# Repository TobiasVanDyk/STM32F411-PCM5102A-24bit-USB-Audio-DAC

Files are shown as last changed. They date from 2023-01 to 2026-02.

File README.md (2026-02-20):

# STM32F411 PCM5102A 24bit USB Audio DAC

This is an inexpensive USBAudio DAC that supports 24-bit resolution audio at 44.1kHz, 48kHz or 96kHz. It uses an STM32F411 Black Pill with two different i2s PCM5102A DAC modules - they differ in size and design. The software is based on this [**STM32F4xx USB to I2S DAC Audio Bridge**](https://github.com/har-in-air/STM32F411_USB_AUDIO_DAC) and the [**issue as discussed here**](https://github.com/har-in-air/STM32F411_USB_AUDIO_DAC/issues/7).

Two sizes of the DAC were made - the larger size module uses a PCM5102A DAC with three LDO regulators but with no mute control pin, and the (much) smaller sized DAC uses two LDO regulators and has a mute control pin. 

Note that the [**BambooMaster RP2040 DAC**](https://github.com/BambooMaster/usb_sound_card_hires), which is further [**described here**](https://github.com/TobiasVanDyk/Pico-MCU-from-Raspberry-Pi/tree/main/DacPico), *sounds at least as good as the two STM32F411 DACs presented here*.

The volume control code modifications as discussed in the issue linked to above, was added to a windows port of the code. The Windows 10 STM32CubeIDE project is included here as F411_USB_I2S.zip and the binaries are in build.zip - the hex file can directly be uploaded via the STM32CubeProgrammer using a standard ST-Link module. Note all licenses applicable are the original source code licenses. 

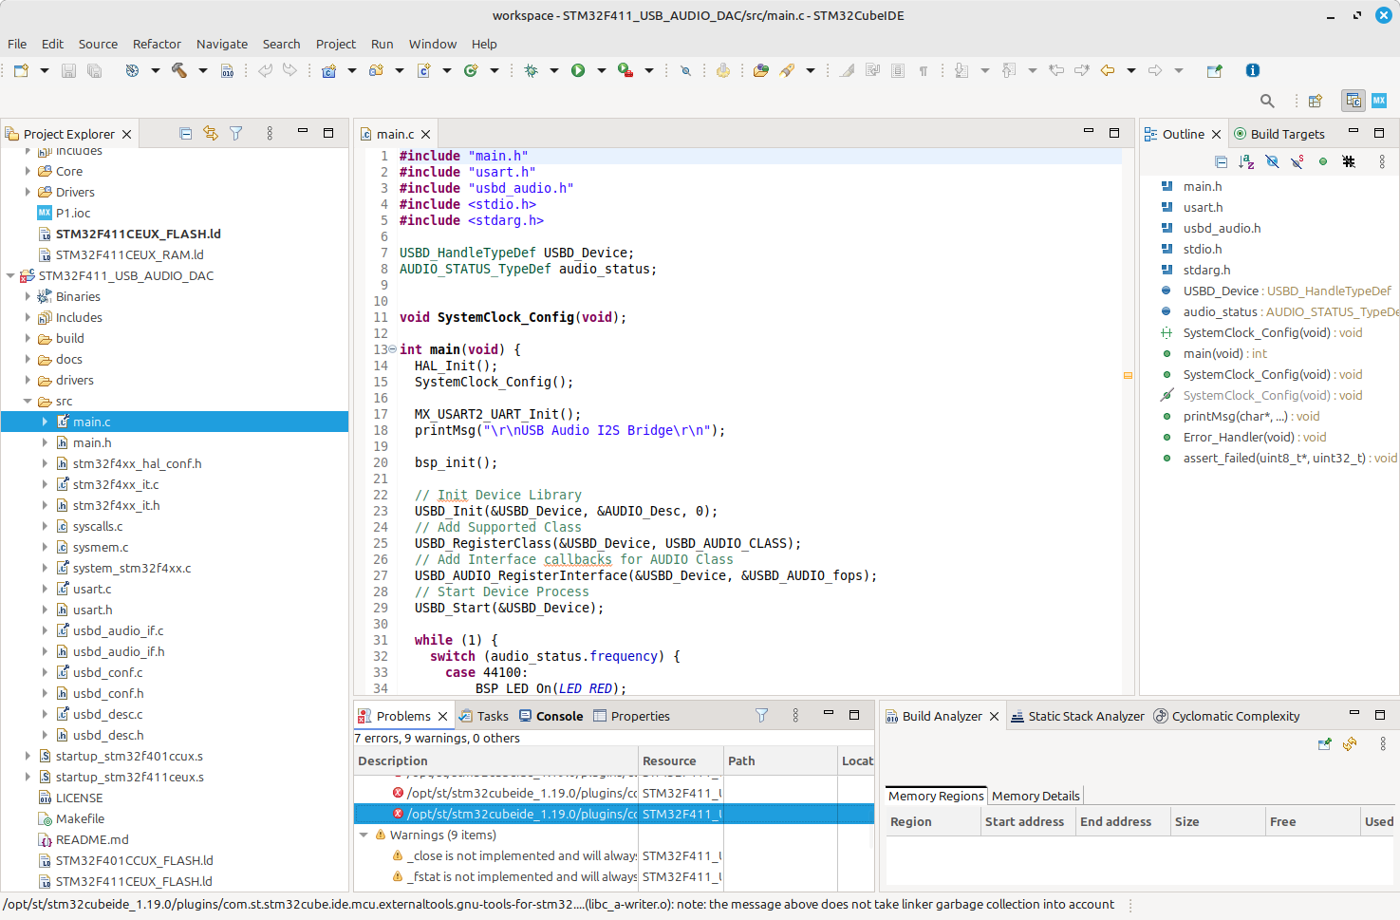
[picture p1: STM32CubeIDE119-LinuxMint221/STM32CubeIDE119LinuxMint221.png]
**Current (July 2025) source and build binaries**, using STM32CubeIDE-1.19.0 and STM32F411-1.28.1, are in the folder [**STM32CubeIDE119-LinuxMint221**](https://github.com/TobiasVanDyk/STM32F411-PCM5102A-24bit-USB-Audio-DAC/blob/main/STM32CubeIDE119-LinuxMint221). They were built using make from a terminal and also using STM32CubeIDE, following the instructions as in [**USB DAC Audio**](https://github.com/har-in-air/STM32F411_USB_AUDIO_DAC). Note that when building using the IDE, there are a **number of linker errors** , but binaries were nonetheless built (and tested). The only source code change made was in main.c to the LED code - using two instead of three LEDs to indicate the three frequency states. The Makefile file was edited for a PCM5102A DAC. Note that the project was imported using **File -> New -> Other -> C/C++ -> Makefile Project with existing code** - an empty project named P1 was created before this and used to import the STM32F4xxx firmware (version 1.28.1). Nothing else was required the build the USB-AudioDAC project using STM32CubeIDE. 

The [**previous source**](https://github.com/har-in-air/STM32F411_USB_AUDIO_DAC/issues/14) build binaries are in build-24March2023.zip, built using STM32CubeIDE version 1.12. Older source (Feb 2023) binaries are in build-linux3.tar.gz (Linux Mint 21.1 with STM32CubeIDE 1.11.2), and build-win10.zip (based on project files STM32F411_USB_AUDIO_DAC-win10.zip), built on Windows 10 using the same version of STM32CubeIDE.

For [**older detailed instructions**](https://github.com/TobiasVanDyk/STM32F411-PCM5102A-24bit-USB-Audio-DAC/blob/main/Linux-Mint-211-and-Windows-10-compiling-and-uploading-the-STM32F411-USB-Audio-DAC-fi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), in setting up STMCube 1.11 and 1.12, refer to the PDF document: Installing STM32CubeIDE in Linux Mint 21.1 and in Windows 10, and compiling and uploading the STM32F411 USB Audio DAC firmware.

The USB DAC with the volume control identifies as PCM5102A DAC and the older non-volume version as USB to I2S DAC - refer to the screen dump shown below.

<p align="left">
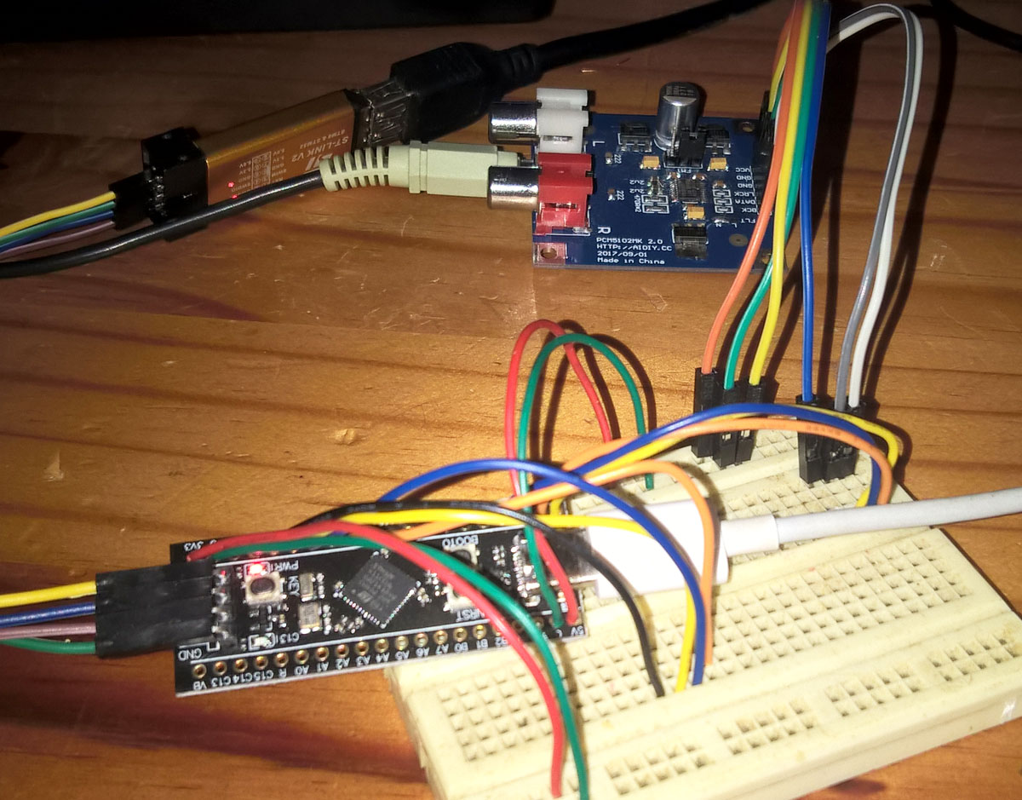
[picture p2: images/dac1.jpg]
 
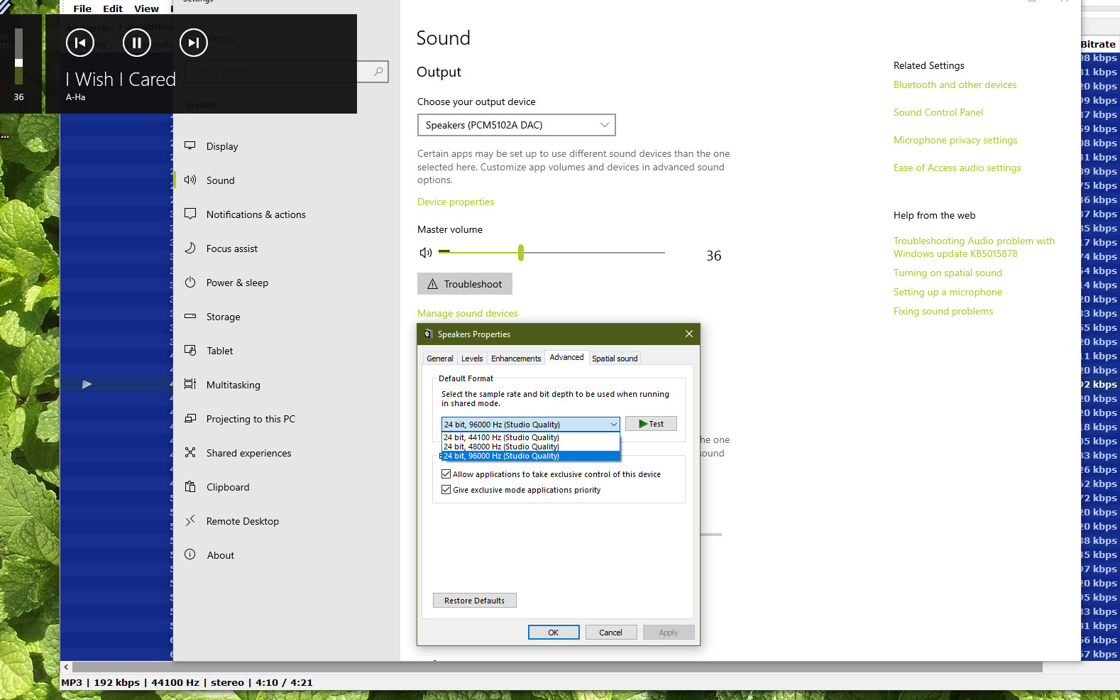
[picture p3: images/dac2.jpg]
 
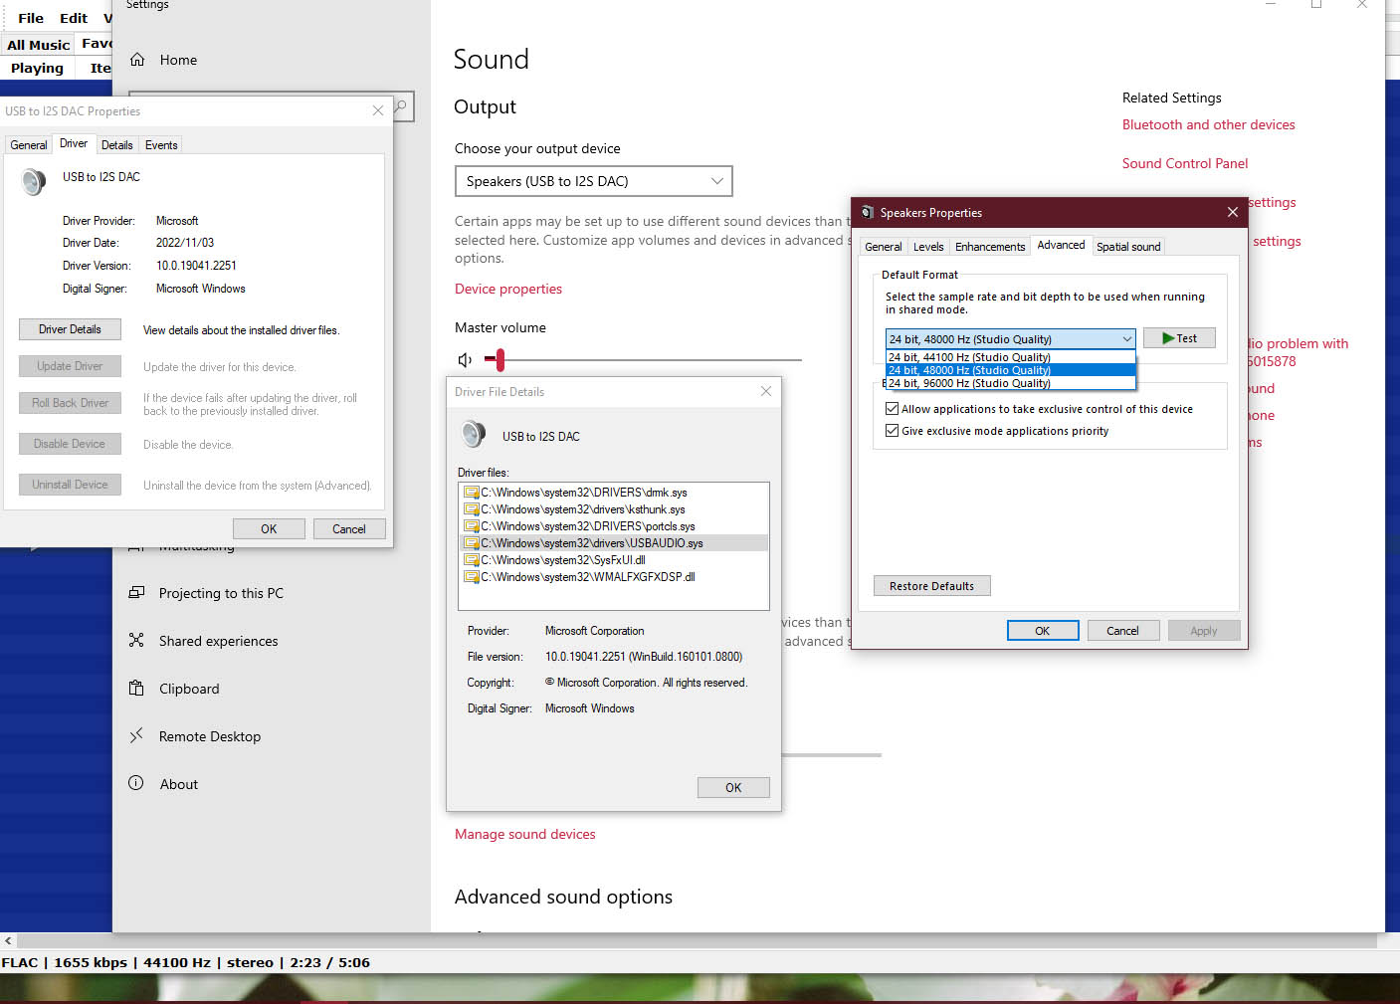
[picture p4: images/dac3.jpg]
 
</p>

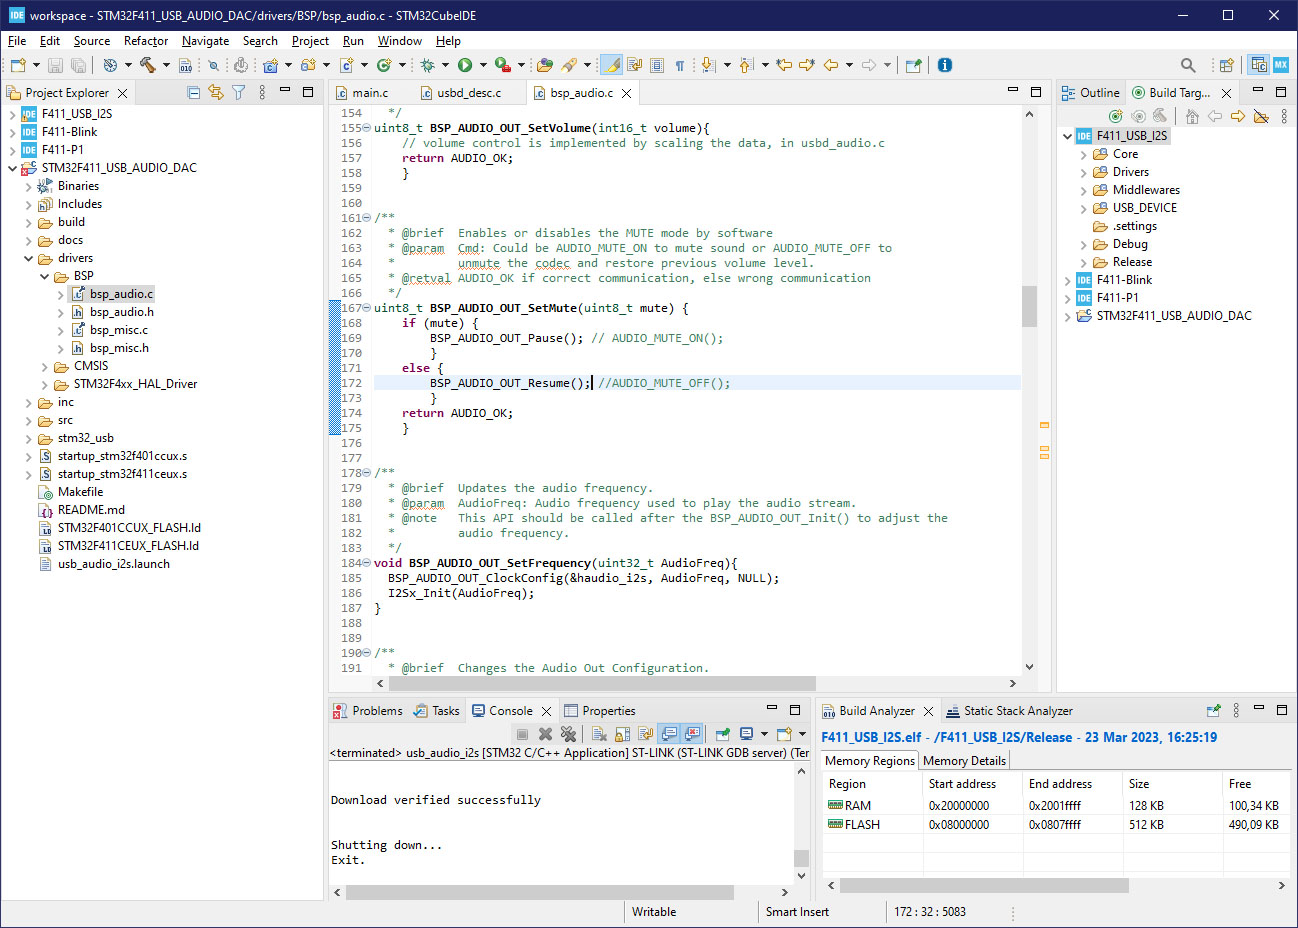
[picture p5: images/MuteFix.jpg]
 The larger sized PCM5102A DAC module used does not have a hardware mute breakout pin. Two changes to bsp_audio.c gives an alternative "volume mute" - the compiled version is in MuteFix.zip. This version uses only the red and green LEDs to indicate the three frequency modes - those changes are in main.c
``` 
uint8_t BSP_AUDIO_OUT_SetMute(uint8_t mute) {
	if (mute) {
		BSP_AUDIO_OUT_Pause();  // AUDIO_MUTE_ON();
		}
	else {
		BSP_AUDIO_OUT_Resume(); // AUDIO_MUTE_OFF();
		}
	return AUDIO_OK;
	}

``` 

**Connections for the larger-sized DAC:**
``` 
F411    PCM5102A    LED    Description 
--------------------------------------------------------------------
5V      VCC
GND     GND            
B13     BCK                I2S_BCK (Bit Clock)
B15     Data               I2S_SDI (Data Input)
B12     LRCK               I2S_WS (LR Clock)
-------------------------------------------------------------------- 
B3                 RED     Fs = 96kHz (all 220R to 3v3)
B6                 GRN     Fs = 48kHz (Red+Green for 44.1kHz)
3v3                LED through-hole common
 
C13             On-board   Diagnostic Blue LED
--------------------------------------------------------------------
``` 
<p align="left">
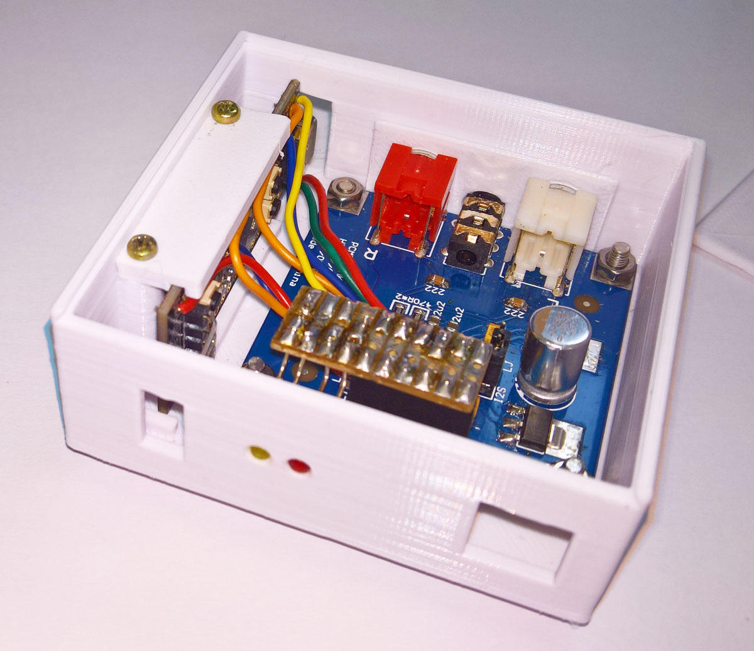
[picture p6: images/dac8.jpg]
 
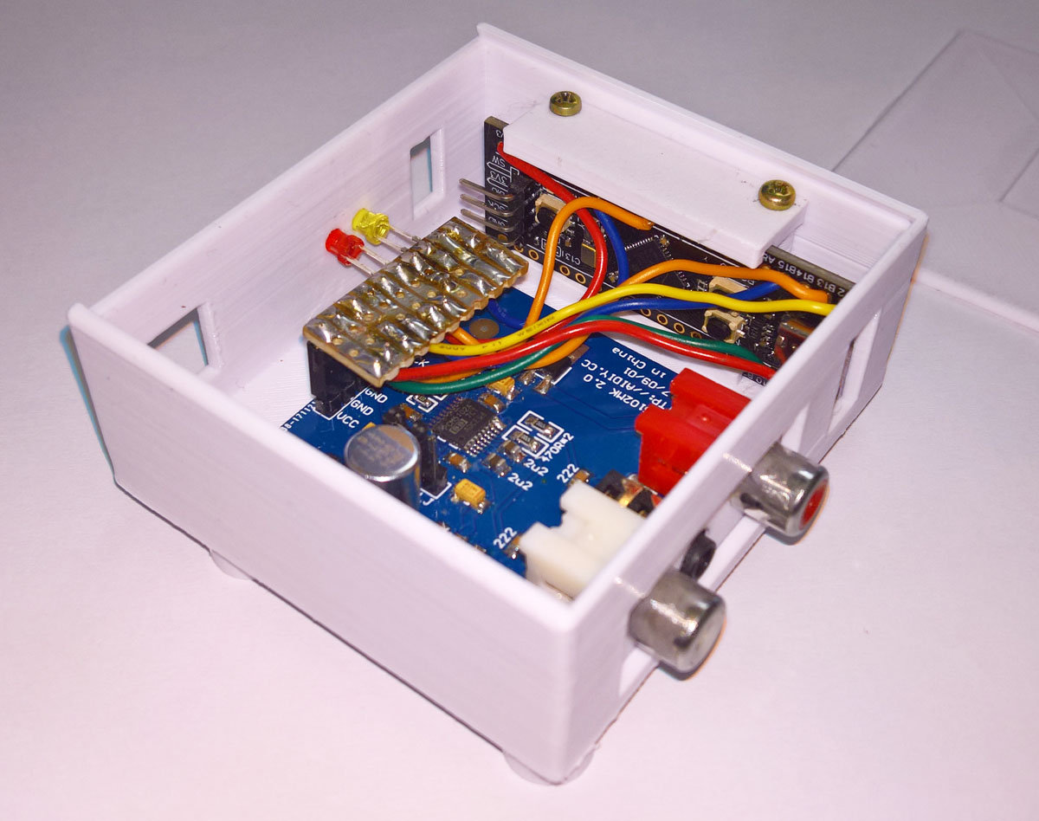
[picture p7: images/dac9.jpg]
 
</p>

The smaller DAC is similarly-sized as the DAC used by [**Har-In-Air**](https://github.com/har-in-air/STM32F411_USB_AUDIO_DAC) - but only two SMD LEDs are used for the 3 frequency indicators. Refer to [**SMD-LED-Resistor**](https://github.com/TobiasVanDyk/STM32F411-PCM5102A-24bit-USB-Audio-DAC/blob/main/images/SMD-LED-Resistor.png) for an approximate layout for the SMD resistors and LEDs. Use a 4-pin JST male connector at the bottom of the STM32F411 board.

The source+build and the build-folder-only are included here as Small-USBAUDIODAC-Jan2024.zip and Small-build-Jan2024.zip - insignificant changes were made to main.c, usbd_desc.c, and bsp_audio.c.

The 3D case files are in the STL folder named Small*.stl. It is based on this [**PCB-holder SCAD model**](https://www.thingiverse.com/thing:4061855). Various length and width parameters for other MCU-boards (namely an RP2040 Pico, STM32F103 Blue Pill, STM32F411 Black Pill, and a Teensy 4.1) are in the file [**pcbholder-params**](https://github.com/TobiasVanDyk/STM32F411-PCM5102A-24bit-USB-Audio-DAC/blob/main/stl/pcbholder-params.txt) also in the STL folder.

**Connections for the smaller-sized DAC:**
``` 
F411    PCM5102A    LED    Description 
--------------------------------------------------------------------------------------
5V      VCC
GND     GND            
B13     BCK                I2S_BCK (Bit Clock)
B15     DIN                I2S_SDI (Data Input)
B12     LCK                I2S_WS (LR Clock)
B8      XMT                Mute Control

Bridge the SCK pads on top with solder to connect it to earth
No other solder bridges are required for the 4 pad-sets on the other side of the PCB
--------------------------------------------------------------------------------------- 
B3                 GRN     Fs = 96kHz (both SMD-LEDs 1k ohm to 3v3)
B6                 RED     Fs = 48kHz (Red+Green for 44.1kHz)
3v3                LED SMD-1206 common
 
C13             On-board   Diagnostic Blue LED
---------------------------------------------------------------------------------------
``` 
<p align="left">
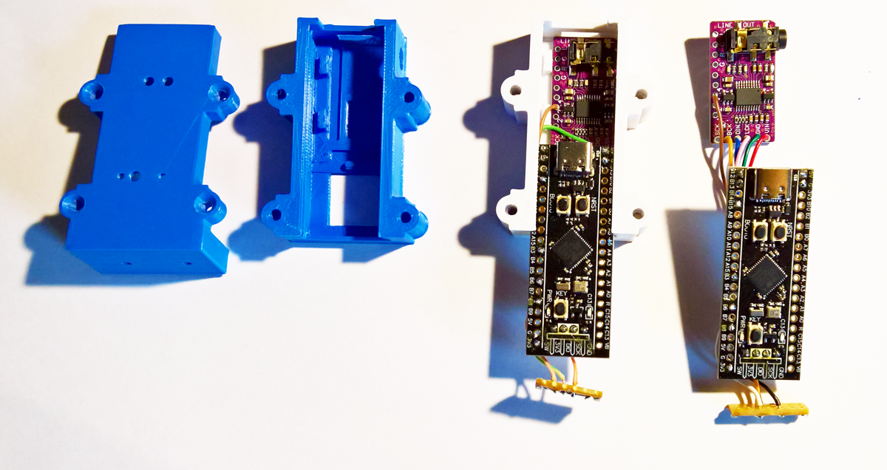
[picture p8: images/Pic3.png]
 
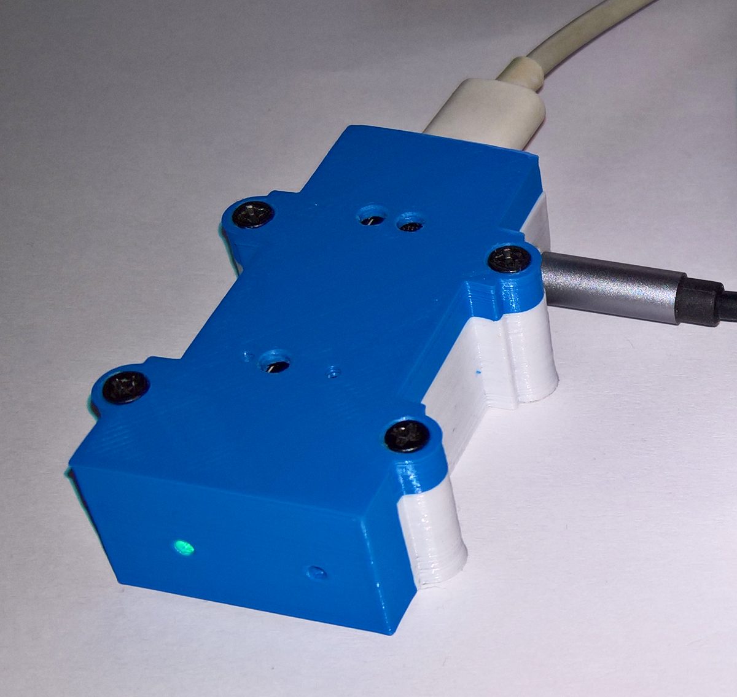
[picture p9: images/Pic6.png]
 
</p>

The [**STM32F11 can be obtained here**](https://www.robotics.org.za/STM32F411CEU6-MOD) and the [**larger PCM5102A DAC module here**](https://www.robotics.org.za/PCM5102-MOD-RCA) or the **smaller-sized DAC** [**here**](https://botshop.co.za/products/pcm5102-dac-i2s-interface-decoder-sound-card-board-digital-audio-gy-pcm5102-phat-format-player-module-for-raspberry-pi) or [**here**](https://www.robotics.org.za/PCM5102-MOD).

<p align="left">
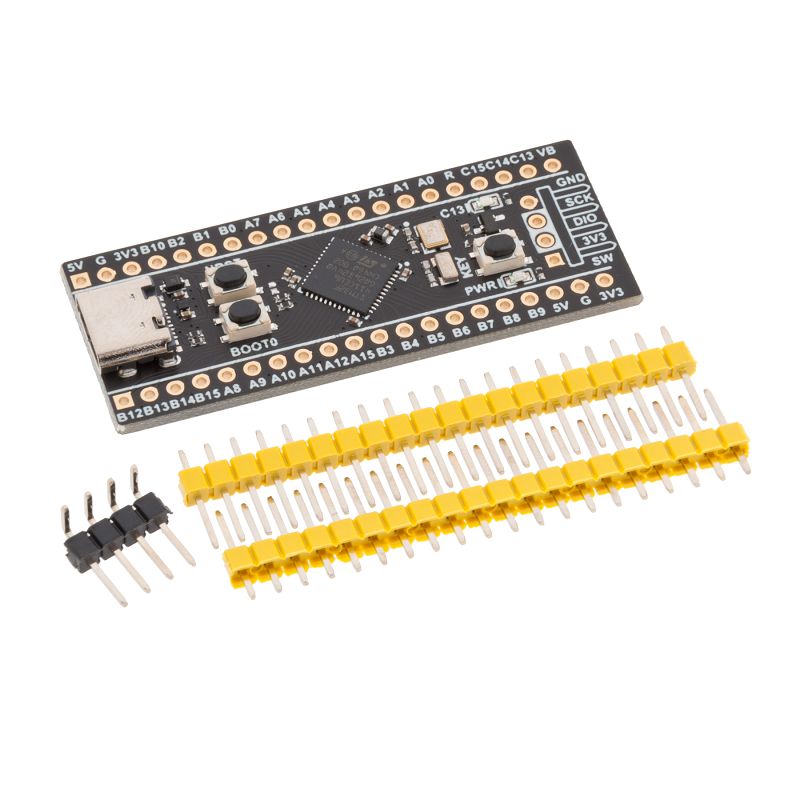
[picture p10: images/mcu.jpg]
   
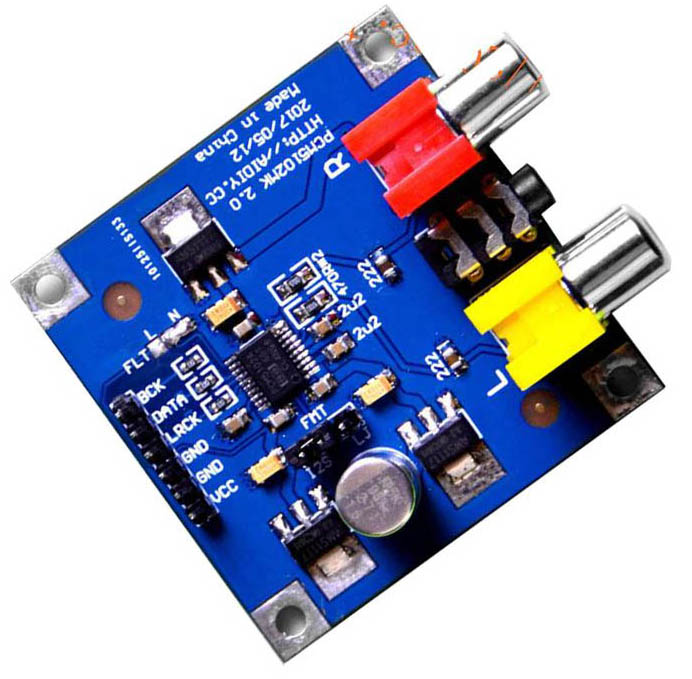
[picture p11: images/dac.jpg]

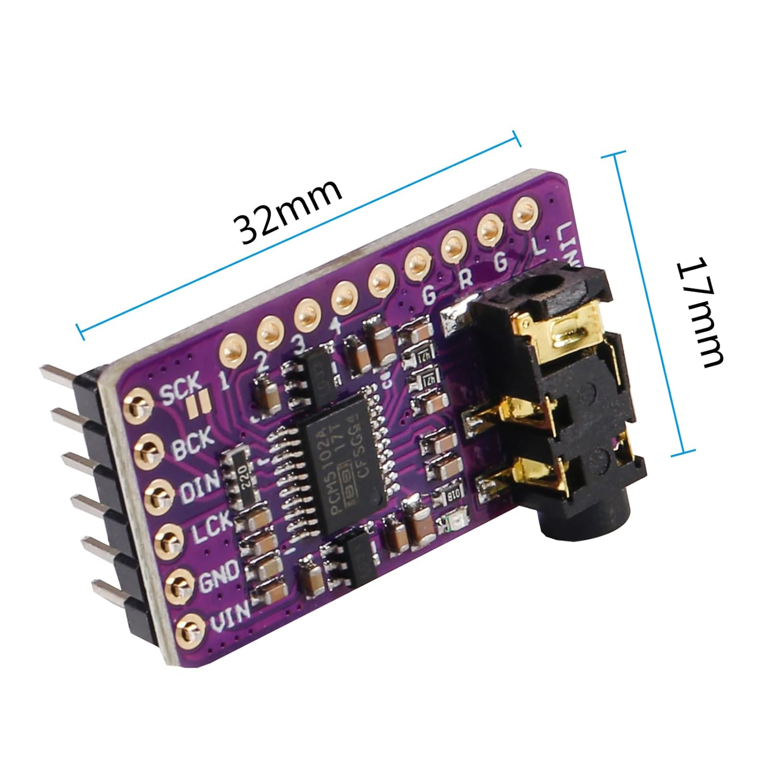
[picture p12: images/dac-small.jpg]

</p>

This DAC is the perfect companion for the [**1976 November Wireless World An Advanced Preamplifier by Douglas Self**](https://github.com/TobiasVanDyk/STM32F411-PCM5102A-24bit-USB-Audio-DAC/wiki)). 

There are a number of variations of the (Chinese) PCM5102A modules - where available schematics of single, double and triple (as used here) LDO regulator modules are shown below.

<p align="left">
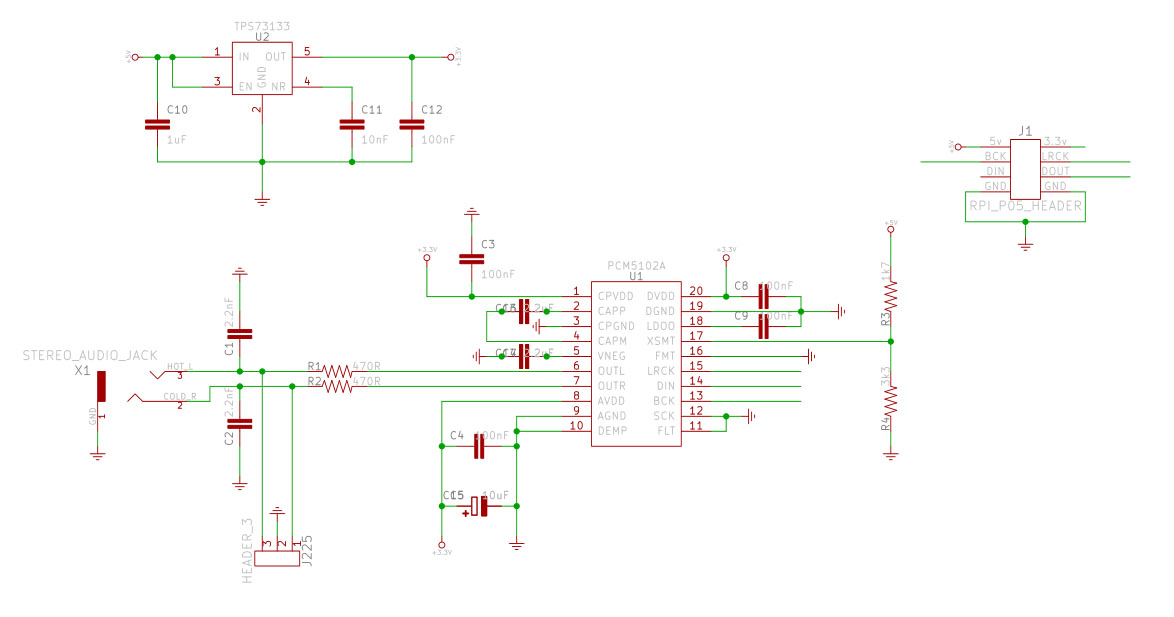
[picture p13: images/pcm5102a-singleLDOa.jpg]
 
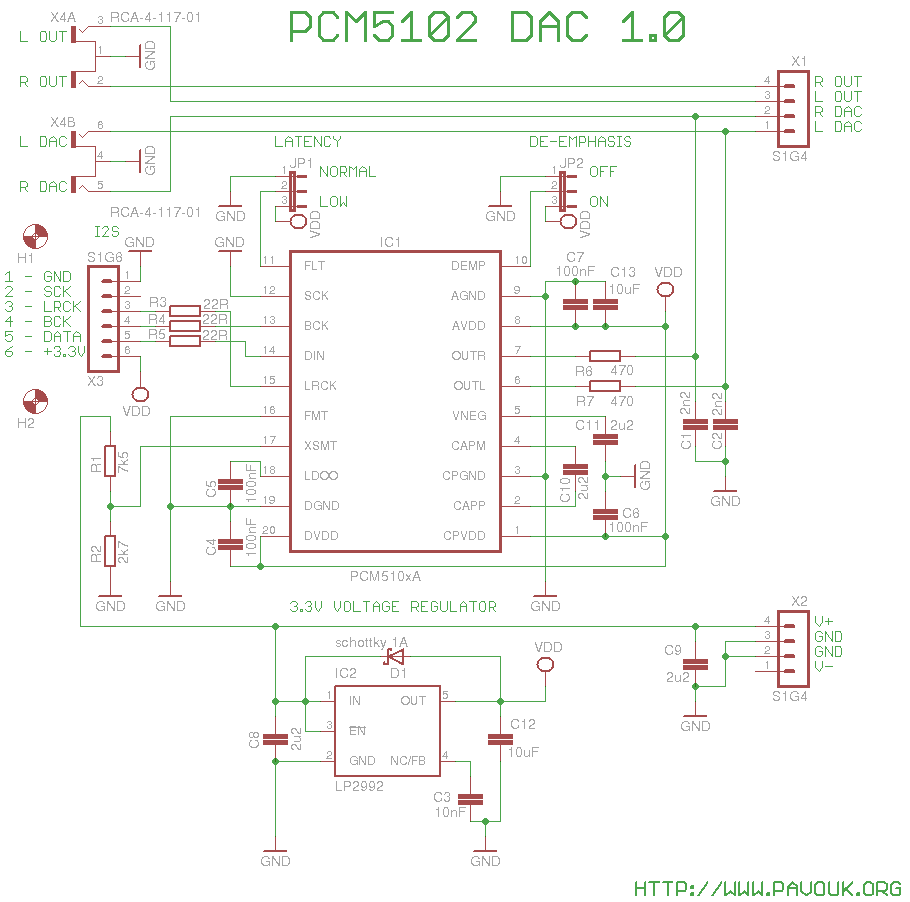
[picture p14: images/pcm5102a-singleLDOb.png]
 
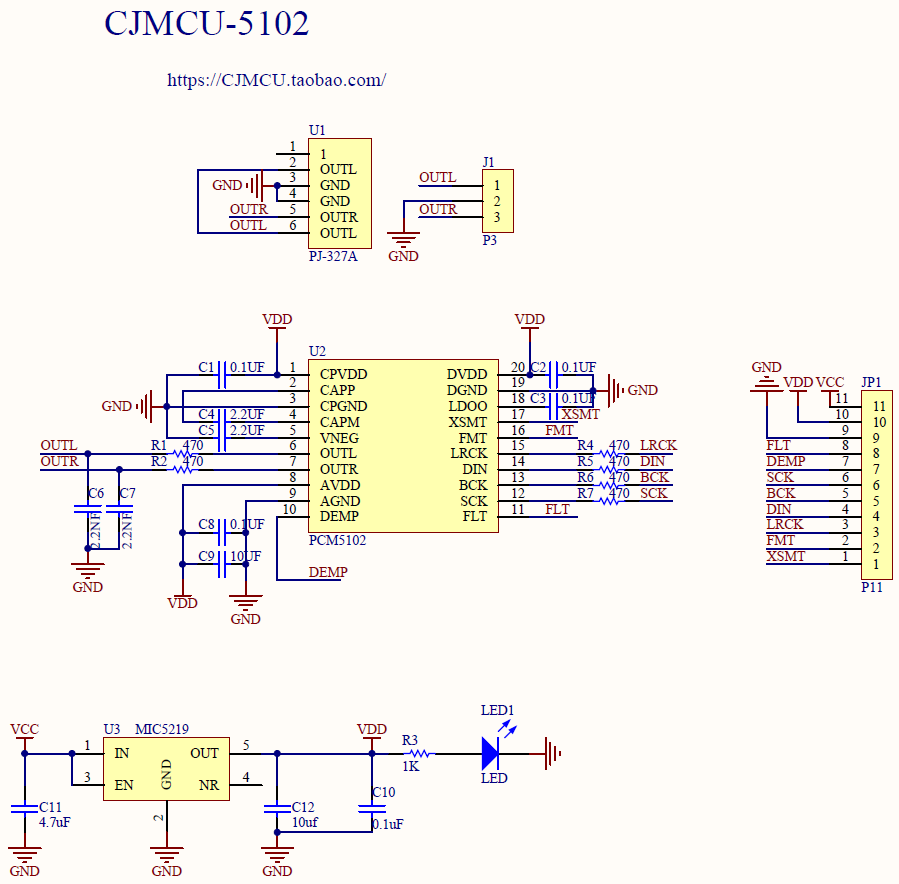
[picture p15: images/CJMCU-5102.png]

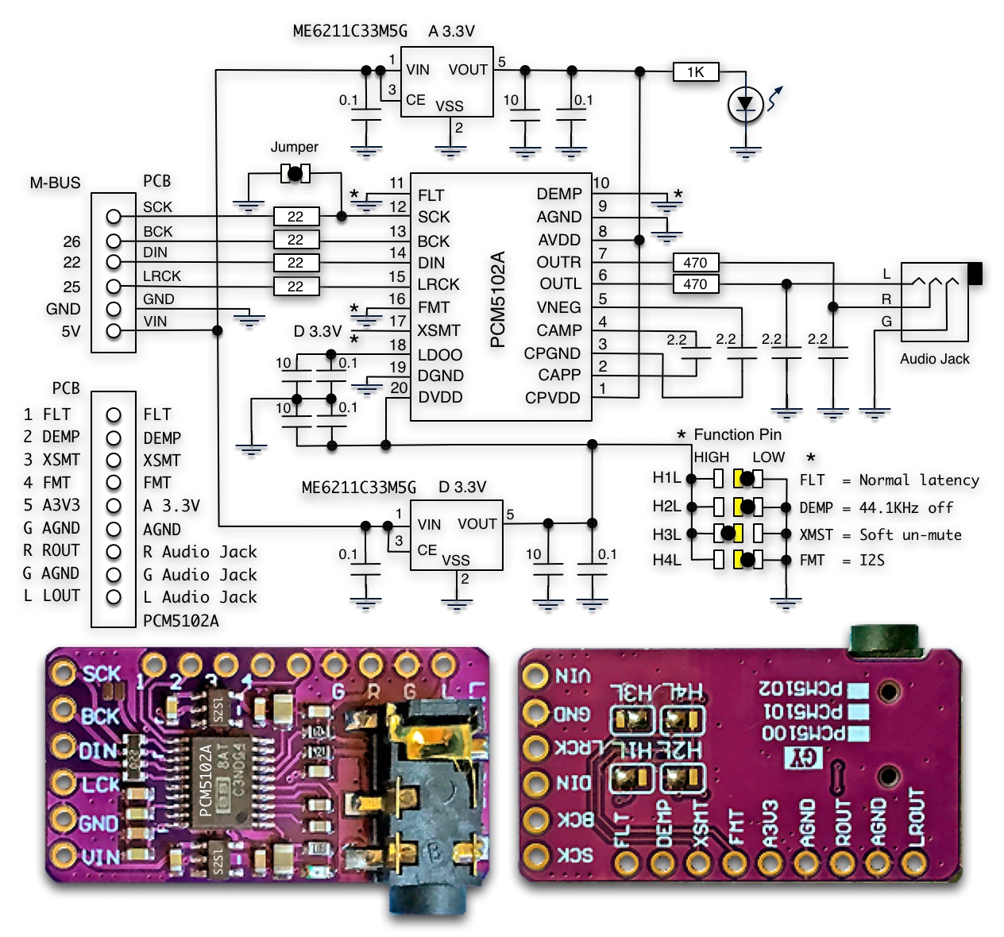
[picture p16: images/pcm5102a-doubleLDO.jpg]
 
</p>
<p align="left">
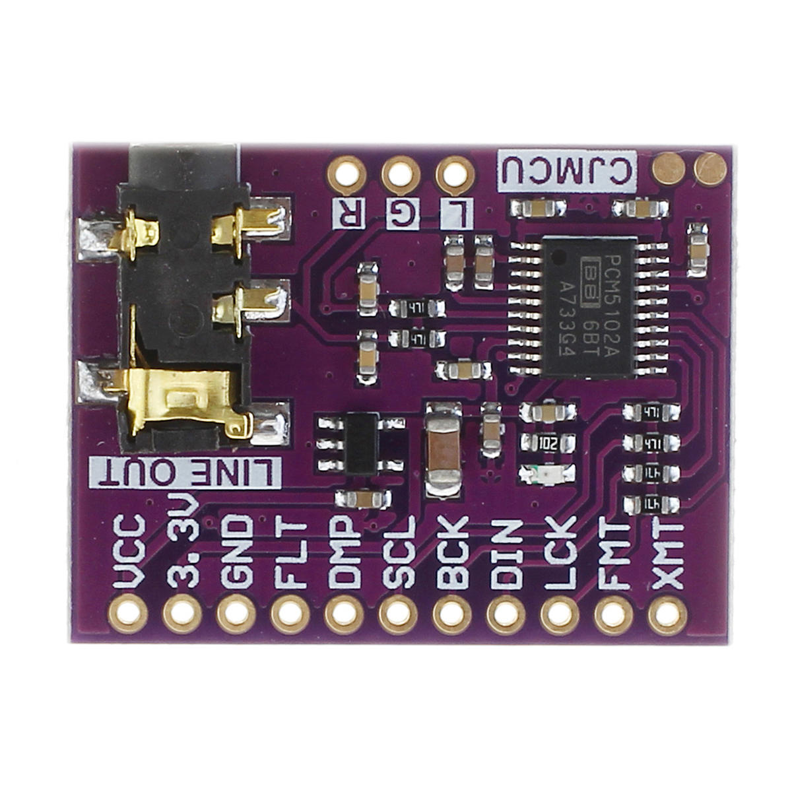
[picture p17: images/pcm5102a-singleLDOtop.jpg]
 
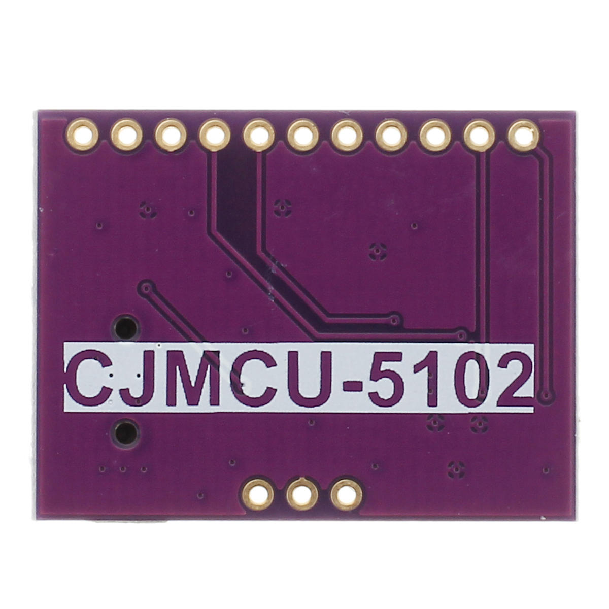
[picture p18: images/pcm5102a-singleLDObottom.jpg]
 
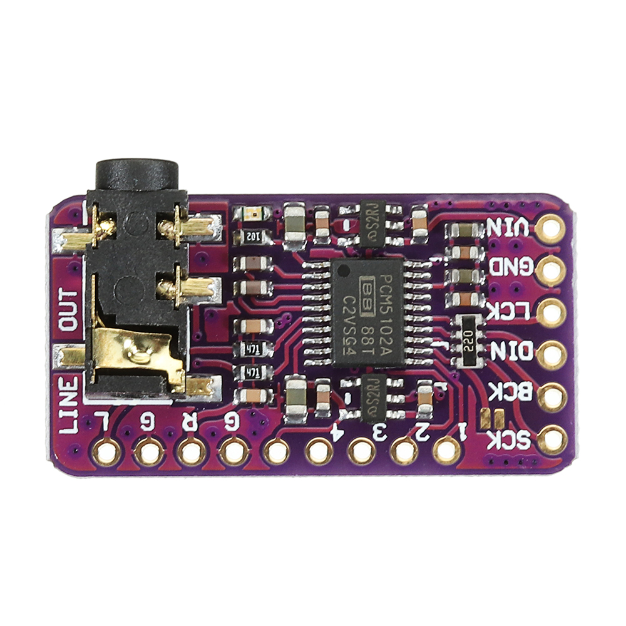
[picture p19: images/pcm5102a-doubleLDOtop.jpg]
 
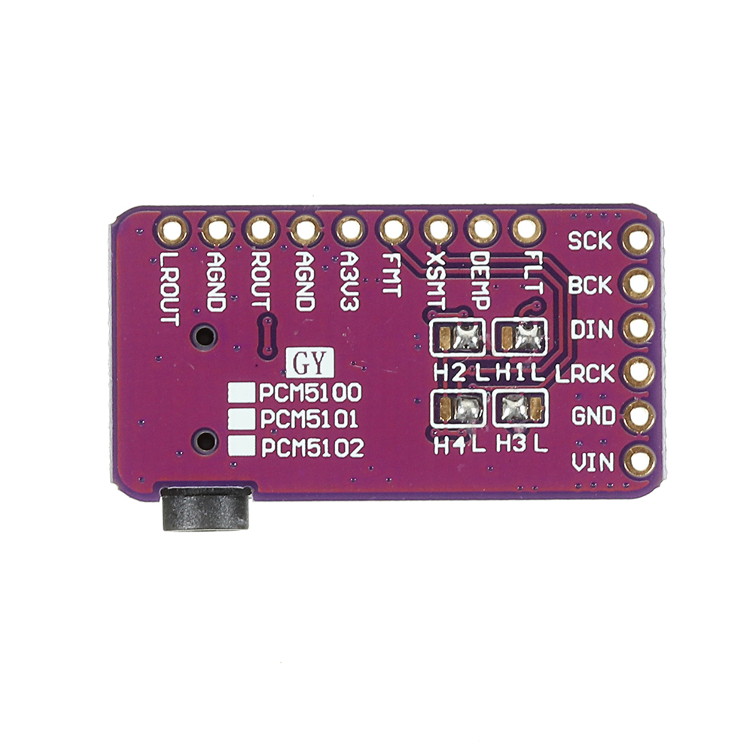
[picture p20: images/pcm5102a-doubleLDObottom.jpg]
	
</p>

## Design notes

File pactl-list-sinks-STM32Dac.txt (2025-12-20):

tobias@pc14400:~$ pactl list sinks
Sink #49
 .......

Sink #67
	State: SUSPENDED
	Name: alsa_output.usb-STM32_Black_Pill_pcm5102A_DAC_337D37793032-00.analog-stereo
	Description: pcm5102A DAC Analog Stereo
	Driver: PipeWire
	Sample Specification: s24le 2ch 48000Hz
	Channel Map: front-left,front-right
	Owner Module: 4294967295
	Mute: no
	Volume: front-left: 35599 /  54% / -15.90 dB,   front-right: 35599 /  54% / -15.90 dB
	        balance 0.00
	Base Volume: 65536 / 100% / 0.00 dB
	Monitor Source: alsa_output.usb-STM32_Black_Pill_pcm5102A_DAC_337D37793032-00.analog-stereo.monitor
	Latency: 0 usec, configured 0 usec
	Flags: HARDWARE HW_MUTE_CTRL HW_VOLUME_CTRL DECIBEL_VOLUME LATENCY 
	Properties:
		alsa.card = "2"
		alsa.card_name = "pcm5102A DAC"
		alsa.class = "generic"
		alsa.components = "USB6666:0123"
		alsa.device = "0"
		alsa.driver_name = "snd_usb_audio"
		alsa.id = "DAC"
		alsa.long_card_name = "STM32 Black Pill pcm5102A DAC at usb-0000:00:14.0-2, full speed"
		alsa.mixer_name = "USB Mixer"
		alsa.name = "USB Audio"
		alsa.resolution_bits = "24"
		alsa.subclass = "generic-mix"
		alsa.subdevice = "0"
		alsa.subdevice_name = "subdevice #0"
		api.alsa.card.longname = "STM32 Black Pill pcm5102A DAC at usb-0000:00:14.0-2, full speed"
		api.alsa.card.name = "pcm5102A DAC"
		api.alsa.path = "front:2"
		api.alsa.pcm.card = "2"
		api.alsa.pcm.stream = "playback"
		audio.channels = "2"
		audio.position = "FL,FR"
		card.profile.device = "1"
		device.api = "alsa"
		device.class = "sound"
		device.id = "56"
		device.profile.description = "Analog Stereo"
		device.profile.name = "analog-stereo"
		device.routes = "1"
		factory.name = "api.alsa.pcm.sink"
		media.class = "Audio/Sink"
		device.description = "pcm5102A DAC"
		node.name = "alsa_output.usb-STM32_Black_Pill_pcm5102A_DAC_337D37793032-00.analog-stereo"
		node.nick = "pcm5102A DAC"
		node.pause-on-idle = "false"
		object.path = "alsa:pcm:2:front:2:playback"
		priority.driver = "1009"
		priority.session = "1009"
		factory.id = "18"
		clock.quantum-limit = "8192"
		client.id = "35"
		node.driver = "true"
		factory.mode = "merge"
		audio.adapt.follower = ""
		library.name = "audioconvert/libspa-audioconvert"
		object.id = "58"
		object.serial = "67"
		api.acp.auto-port = "false"
		api.acp.auto-profile = "false"
		api.alsa.card = "2"
		api.alsa.use-acp = "true"
		api.dbus.ReserveDevice1 = "Audio2"
		device.bus = "usb"
		device.bus-id = "usb-STM32_Black_Pill_pcm5102A_DAC_337D37793032-00"
		device.bus_path = "pci-0000:00:14.0-usb-0:2:1.0"
		device.enum.api = "udev"
		device.icon_name = "audio-card-analog-usb"
		device.name = "alsa_card.usb-STM32_Black_Pill_pcm5102A_DAC_337D37793032-00"
		device.nick = "pcm5102A DAC"
		device.plugged.usec = "29095926"
		device.product.id = "0x0123"
		device.product.name = "pcm5102A DAC"
		device.serial = "STM32_Black_Pill_pcm5102A_DAC_337D37793032"
		device.subsystem = "sound"
		sysfs.path = "/devices/pci0000:00/0000:00:14.0/usb1/1-2/1-2:1.0/sound/card2"
		device.vendor.id = "0x6666"
		device.vendor.name = "Prototype product Vendor ID"
		device.string = "2"
	Ports:
		analog-output: Analog Output (type: Analog, priority: 9900, availability unknown)
	Active Port: analog-output
	Formats:
		pcm

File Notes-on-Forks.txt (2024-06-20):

https://github.com/har-in-air/STM32F411_USB_AUDIO_DAC/network/members

1 Jan 25 2021  https://github.com/jony5-robot/STM32F411_USB_AUDIO_DAC
2 Jun 30 2021  https://github.com/HiIamChaitanya/STM32F411_USB_AUDIO_DAC
3 Aug 23 2022  https://github.com/kagurazakahope/STM32F401_USB_AUDIO_DAC    modified for ES9023 DAC
4 May 28 2022  https://github.com/liushiwei/stm32f4_usbaudio                stm32f4_usbaudio modified for a few other DACs such as pcm1709
5 Jun 26 2021  https://github.com/liushiwei/stm32f4_usbaudio           	    stm32f469-usbaudio for a 32F469IDISCOVERY board *
6 Oct 14 2021  https://github.com/mcginty/wombo_old                    	    changed usb volume section
7 Jan 8  2022  https://github.com/mkullber/STM32F411_USB_AUDIO_DAC          changed usb volume section
8 May 18 2022  https://github.com/neurotoxin78/f411_usb_audio 		    f411_usb_audio possibly use nucleo board
9 Jan 10 2024  https://github.com/DeflateAwning/STM32F411_USB_AUDIO_DAC_PCB Mini-PCB using internal STM32F411 clock

* 10 https://github.com/dragonman225/stm32f469-usbaudio Mute and volume control commands are passed to CS43L22 codec.

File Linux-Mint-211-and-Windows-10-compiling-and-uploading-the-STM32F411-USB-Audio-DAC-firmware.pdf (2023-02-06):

Installing STM32CubeIDE in Linux Mint 21.1 and in Windows 10, and compiling and uploading the STM32F411 USB Audio DAC firmware.

Download STM32CubeIDE for Debian from here: https://www.st.com/en/development-tools/stm32cubeide.html - register or confirm with and email) – the file is named:
en.st-stm32cubeide_1.11.2_14494_20230119_0724.unsigned_amd64.deb_bundle.sh.zip

Extract the file in the Download folder, open a terminal and make it executable then run it:
sudo chmod +x ***.sh
sudo ./***.sh

Ignore the message about the sandbox etc., and reboot for the new udev rules to take effect.

Then run STM32CubeIDE and select a default workspace such as /home/user/STM32CubeIDE/workspace/, and then select File -> New -> STM32Project. Wait a few minutes until the message about a target selector appears then select your STM32 MCU - in this case type STM32F411CEU6 in the top lefthand box then select it in the bottom table and press Next.

Wait until the STM32F411 definition files (and any updates) have been downloaded and installed.

You can then follow the instructions https://community.st.com/s/question/0D53W00000HNrEsSAL/how-to-installstm32cubeide-on-ubuntu (https://community.st.com/s/question/0D53W00000HNrEsSAL/how-to-install-stm32cubeide-on-ubuntu) further for doing a quick blinky test, or just cancel the project and start with the new USB Audio DAC project below. Remember to connect the MCU and the ST-Link-USB adapter to the PC.

Download the zip file from here https://github.com/har-in-air/STM32F411_USB_AUDIO_DAC and extract it in /home/user/STM32CubeIDE/workspace/. Then remove the -main part of the extracted folder and open CubeIDE.

Choose File -> New -> Makefile Project with Existing Code, browse to the STM32F411_USB_AUDIO_DAC folder and select it. Choose MCU Arm GCC – see below, and press Finish:

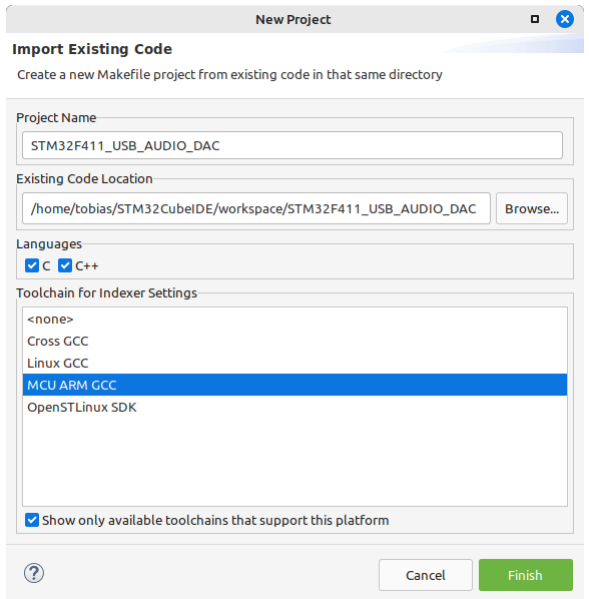
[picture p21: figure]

Open the Makefile and comment out the STM32F401 section and uncomment the STM32F411 section (3 lines each), and save the makefile. Then press Project -> Build Project - it should complete the build - see below:

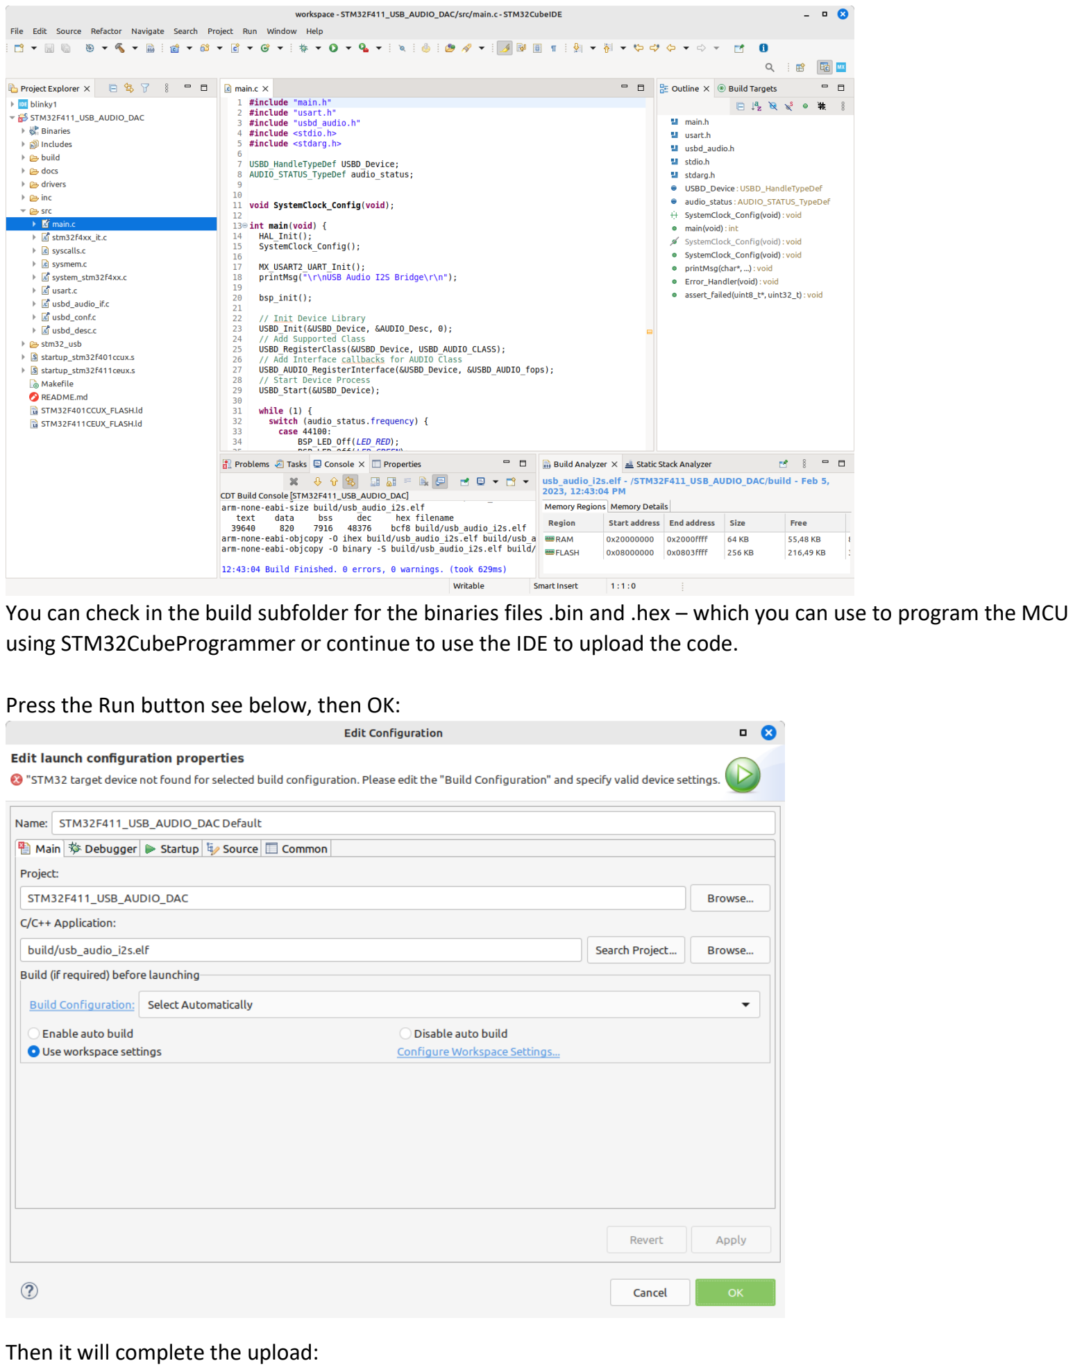
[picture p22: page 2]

You can check in the build subfolder for the binaries files .bin and .hex – which you can use to program the MCU using STM32CubeProgrammer or continue to use the IDE to upload the code.

Press the Run button see below, then OK:

Then it will complete the upload:

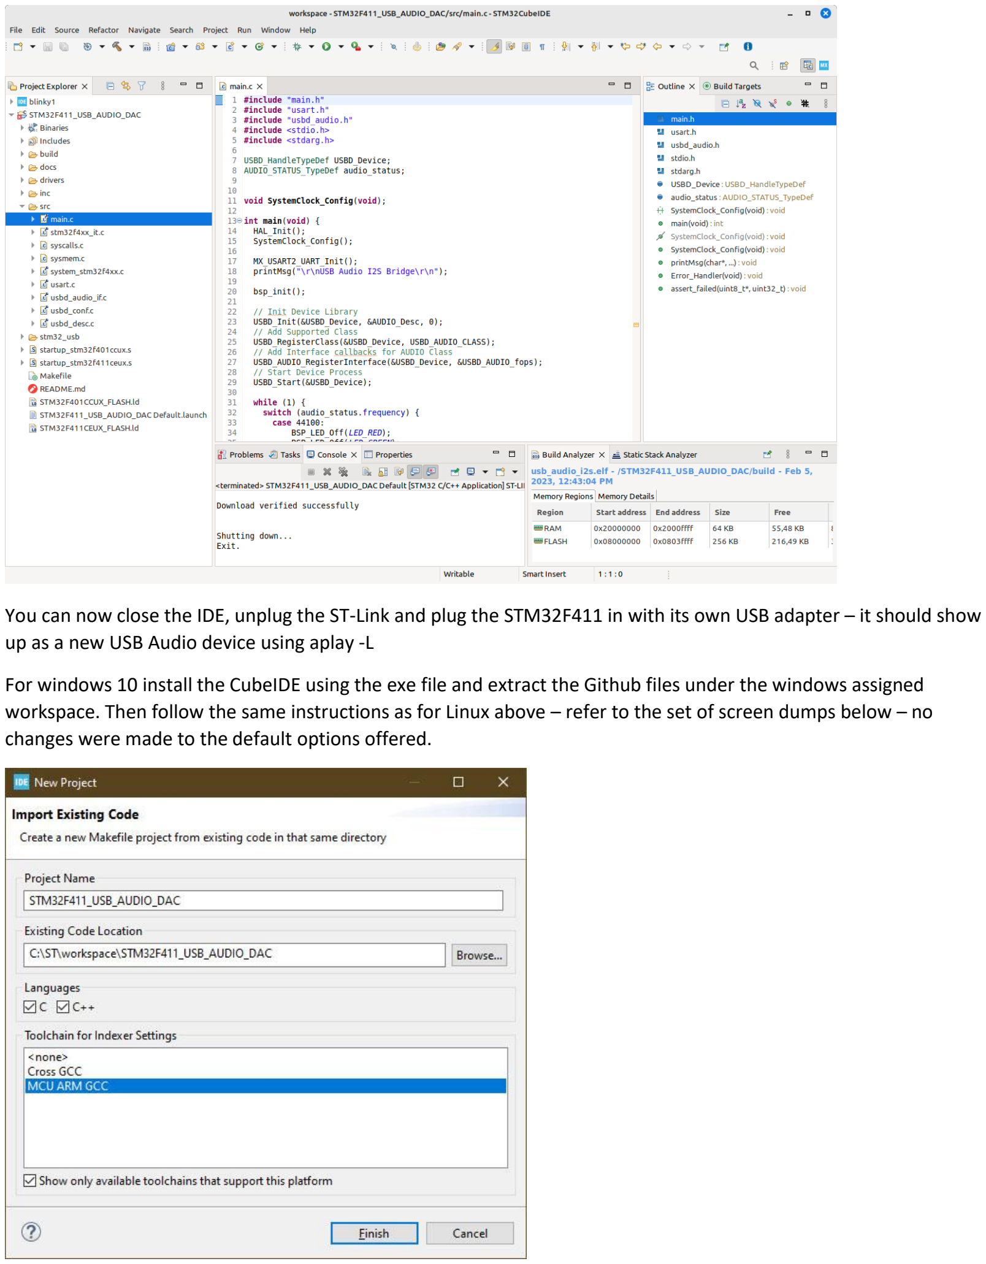
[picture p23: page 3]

You can now close the IDE, unplug the ST-Link and plug the STM32F411 in with its own USB adapter – it should show up as a new USB Audio device using aplay -L

For windows 10 install the CubeIDE using the exe file and extract the Github files under the windows assigned workspace. Then follow the same instructions as for Linux above – refer to the set of screen dumps below – no changes were made to the default options offered.

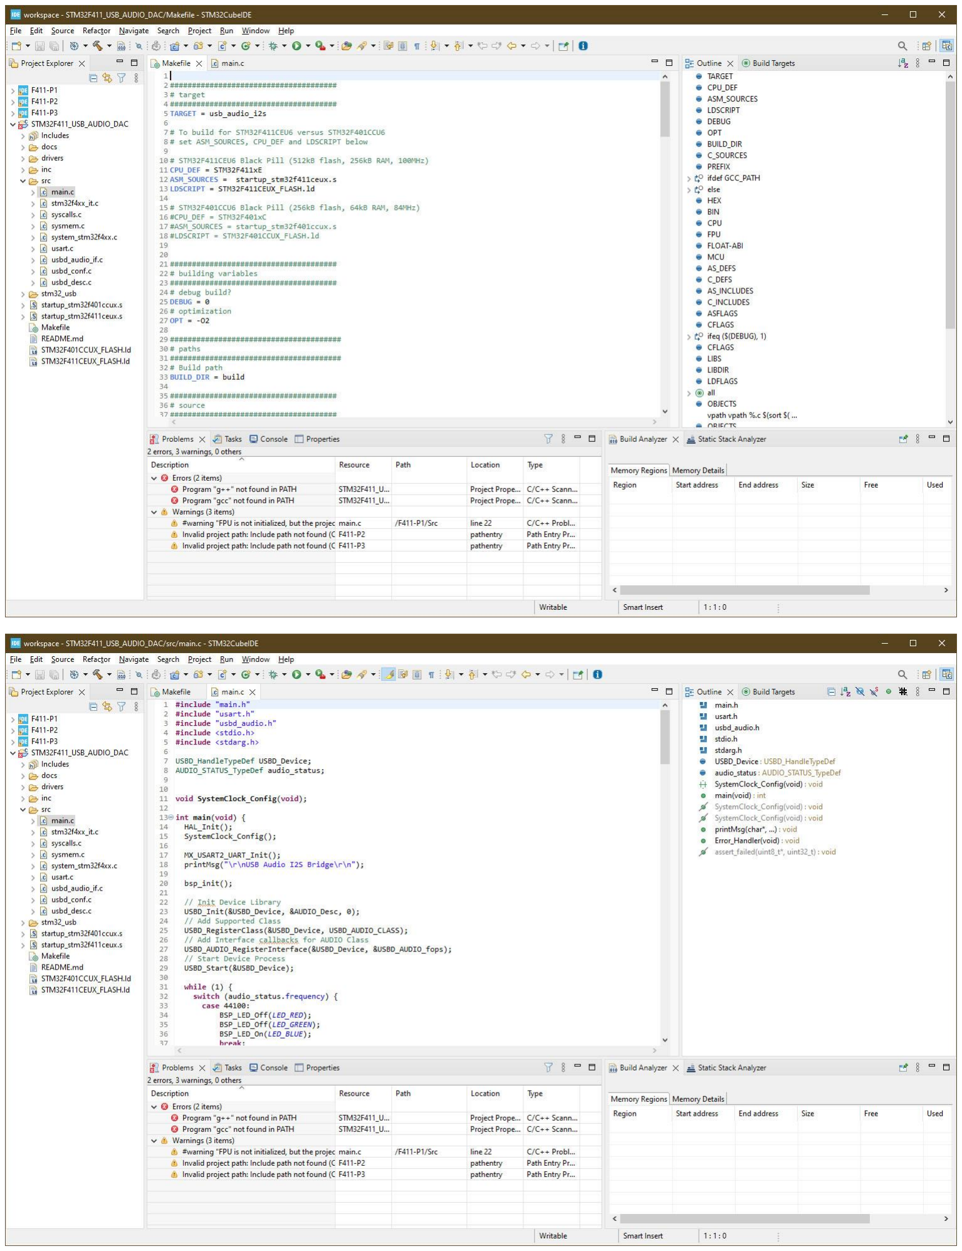
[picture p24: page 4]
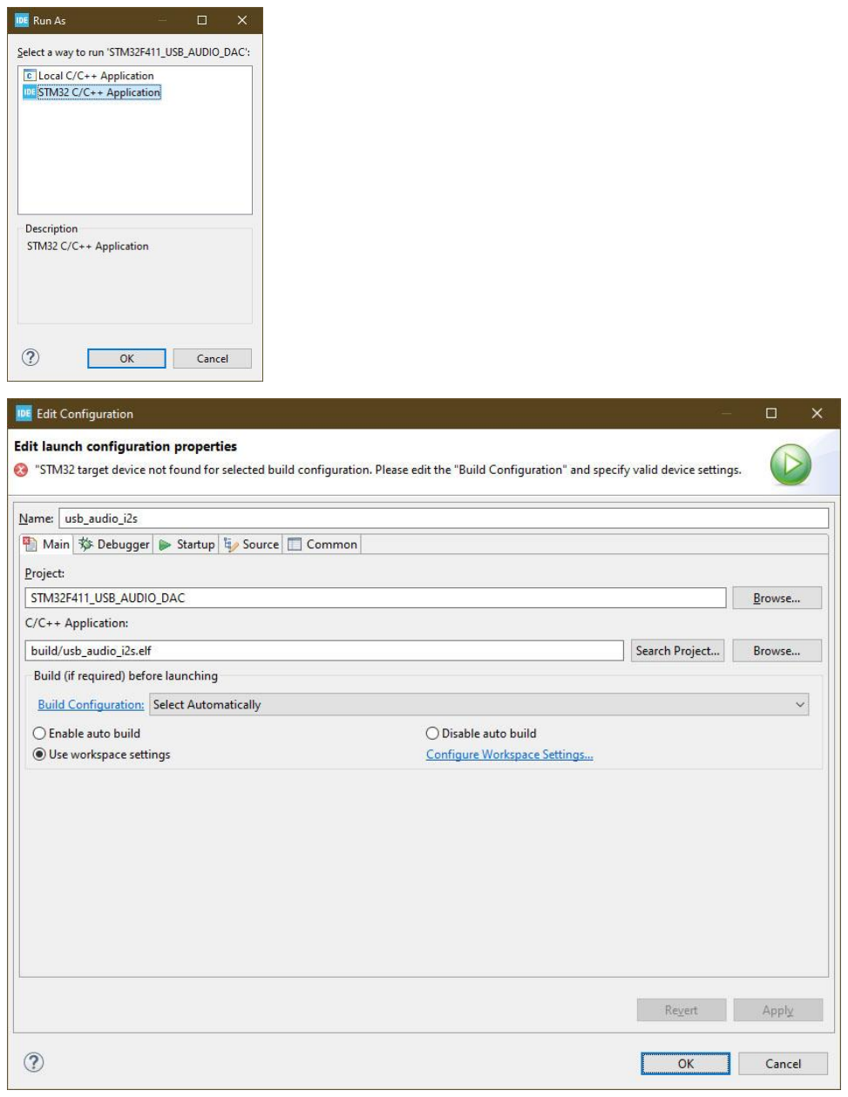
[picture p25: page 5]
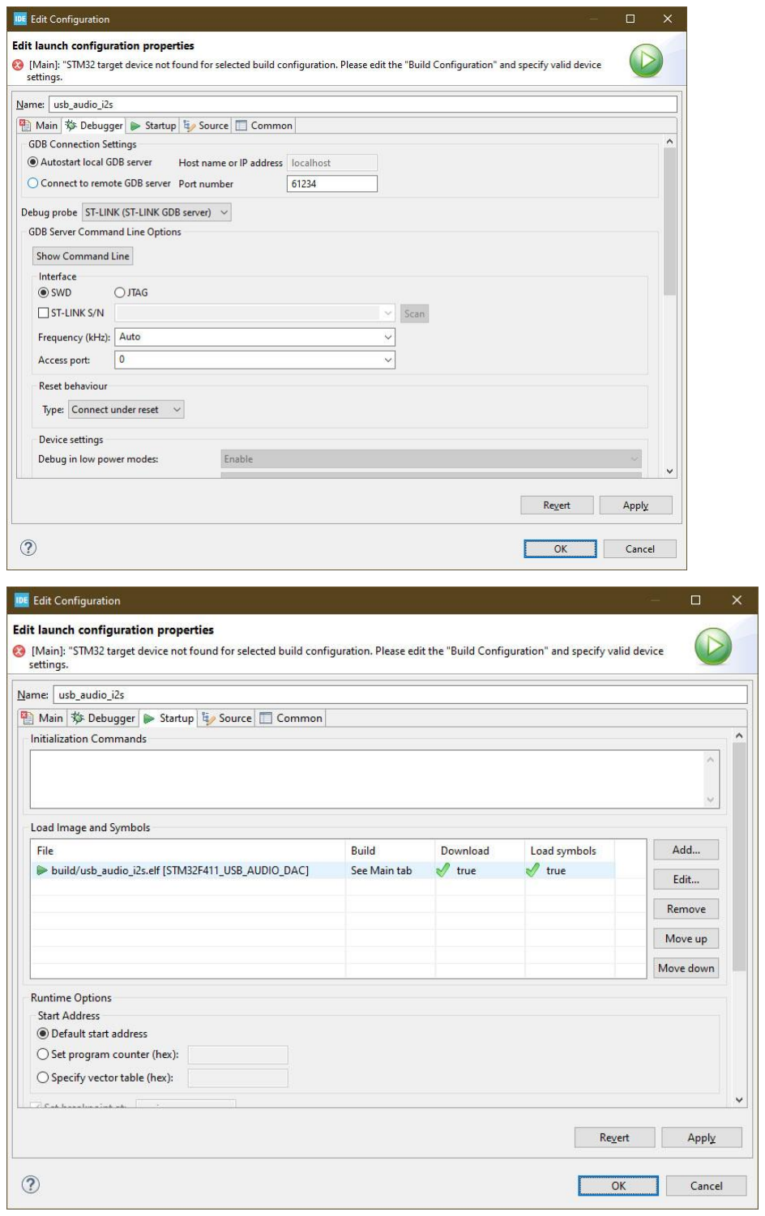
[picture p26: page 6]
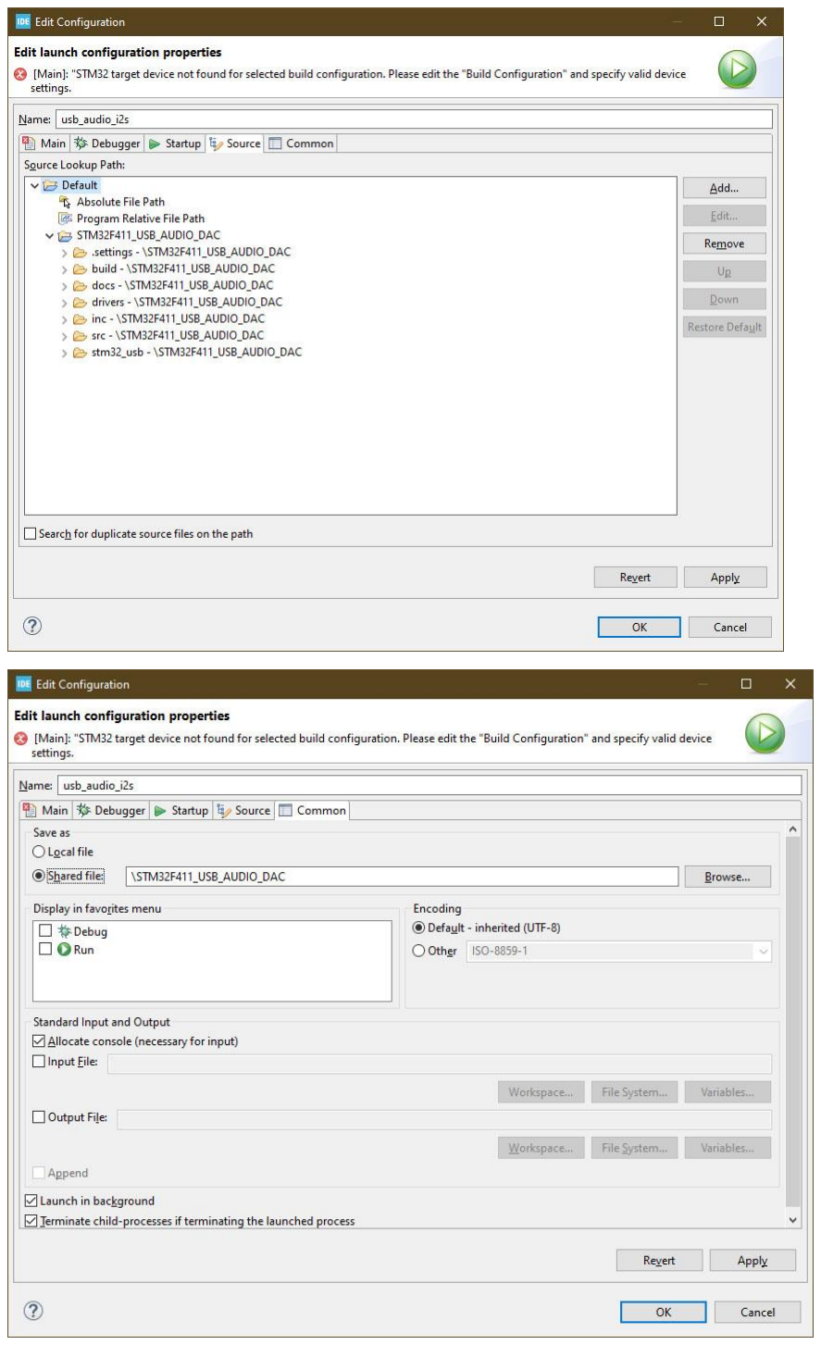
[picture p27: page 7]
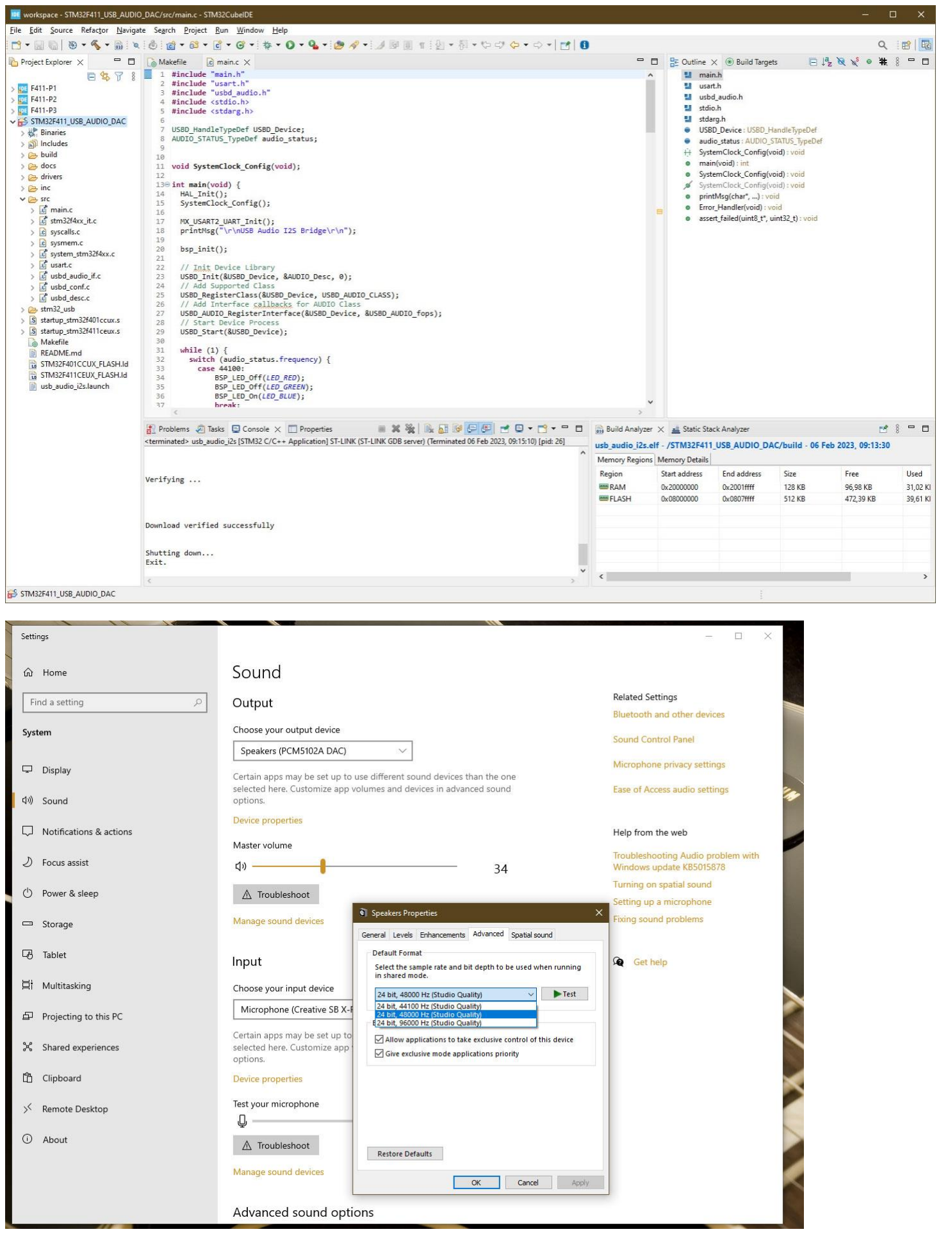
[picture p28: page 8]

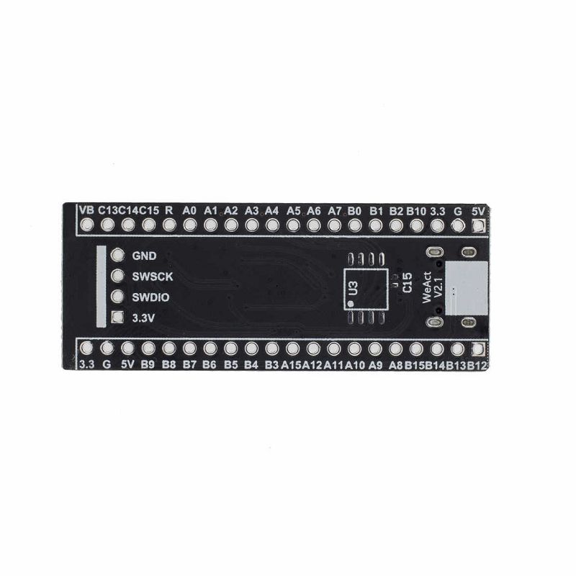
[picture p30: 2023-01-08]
images/mcub.jpg

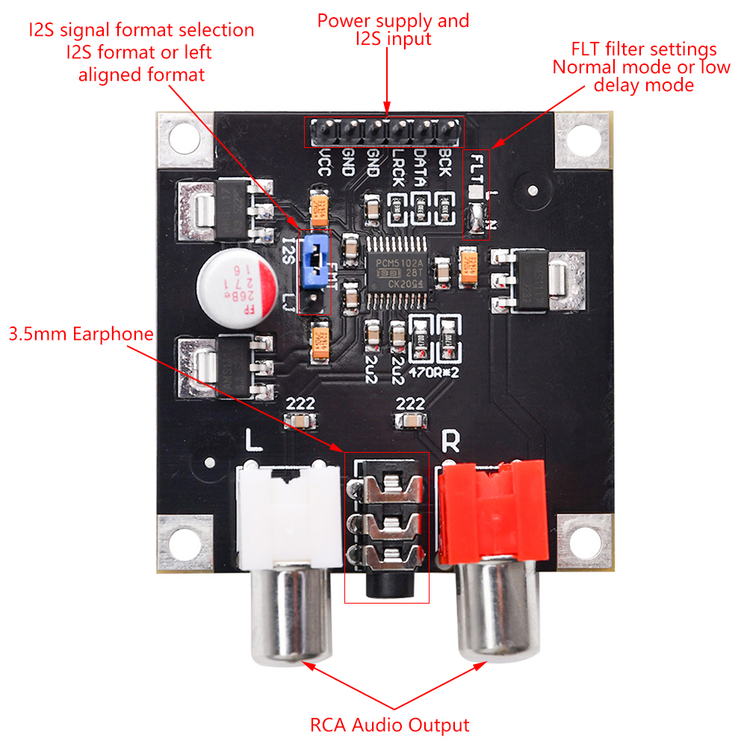
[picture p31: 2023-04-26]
images/pcm5102a-tripleLDO.jpg

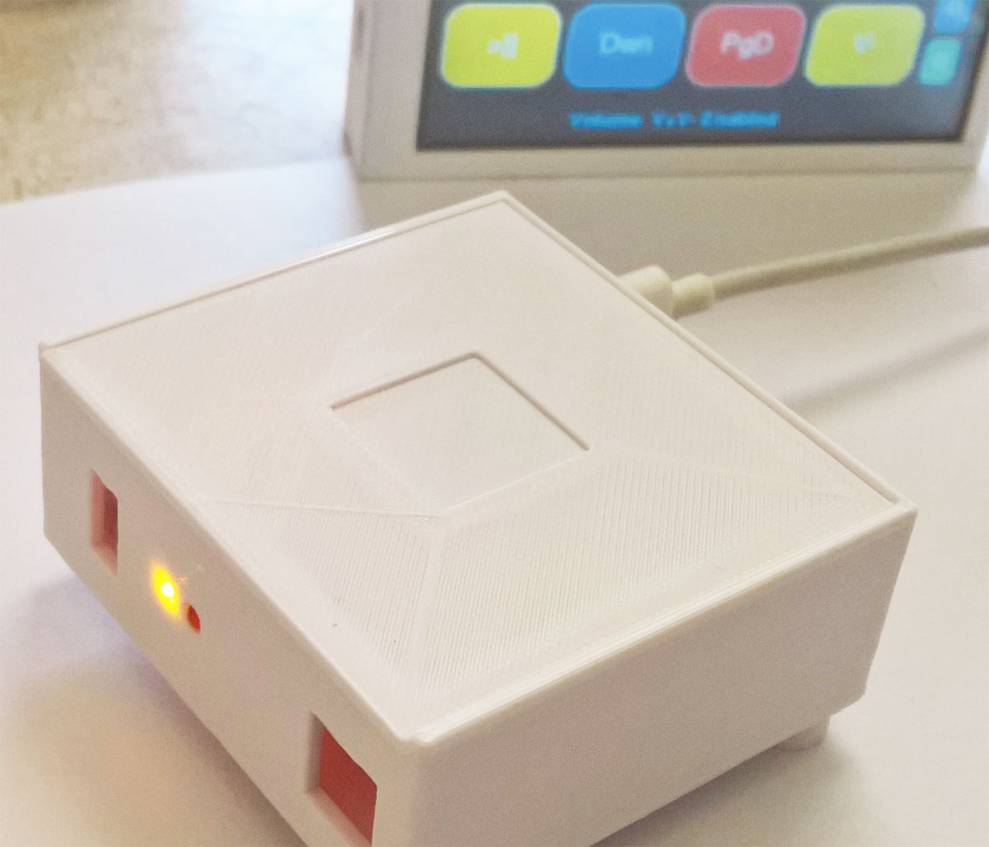
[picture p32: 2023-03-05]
images/dac12.jpg

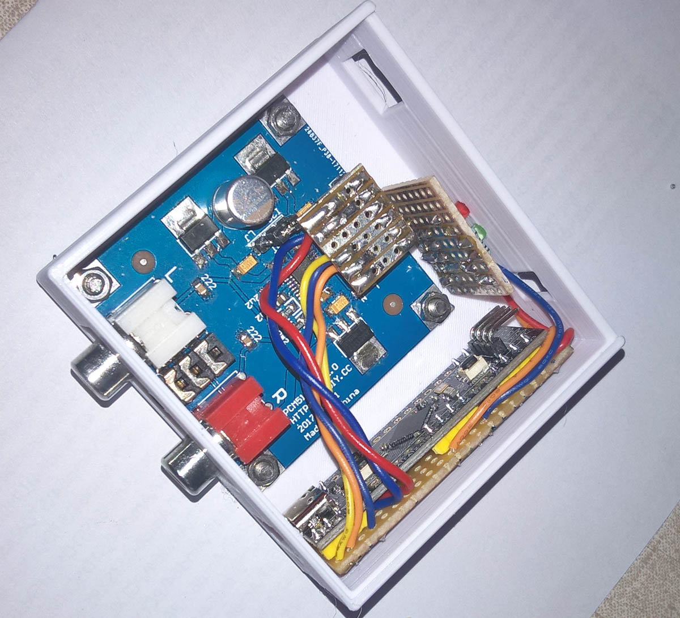
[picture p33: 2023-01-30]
images/case1.jpg

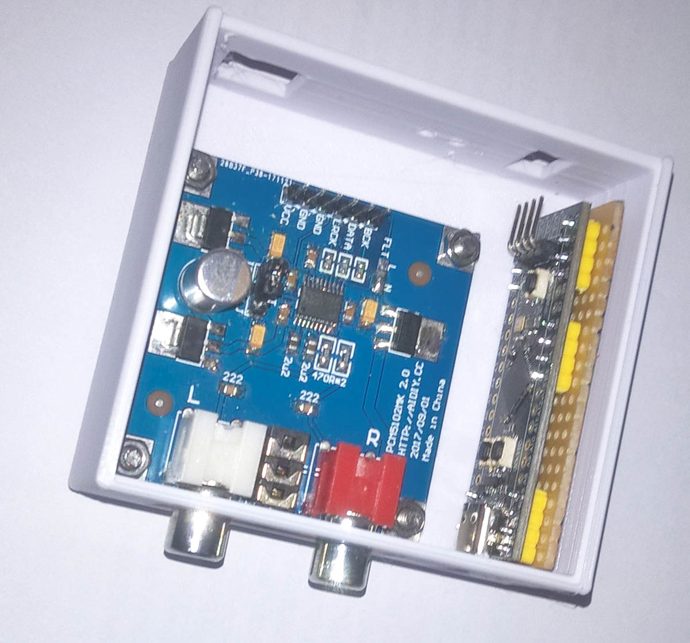
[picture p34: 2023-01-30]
images/case0.jpg

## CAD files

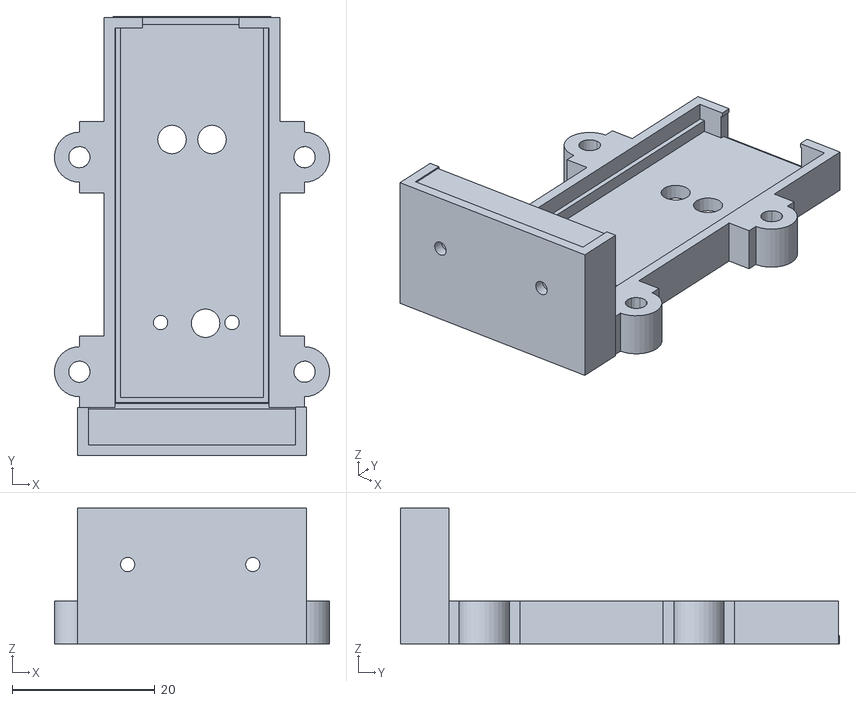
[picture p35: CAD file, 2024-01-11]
stl/Small-PCM5102A-STM32F411DAC-Topc.stl
38.5 x 61.4 x 19.0

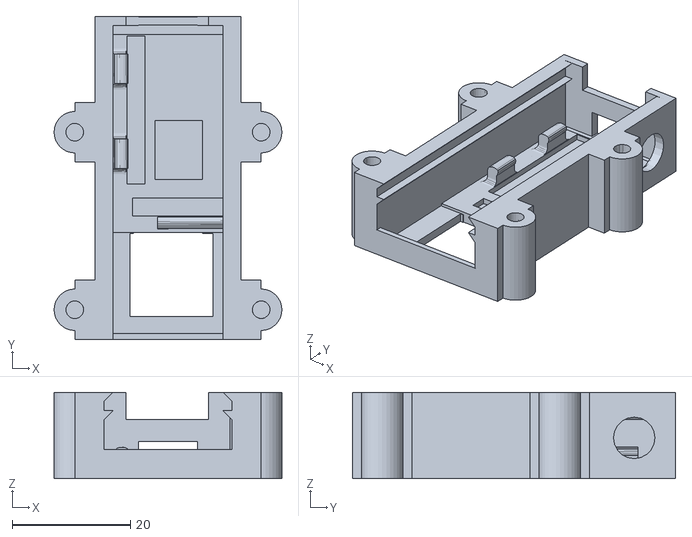
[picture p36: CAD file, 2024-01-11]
stl/Small-PCM5102A-STM32F411DAC-Bottom.stl
38.5 x 54.6 x 14.6

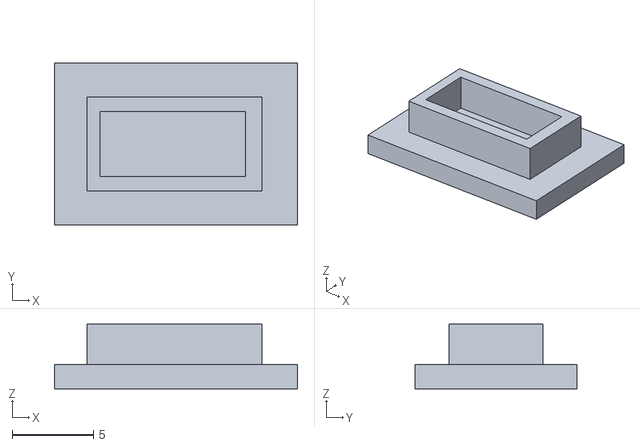
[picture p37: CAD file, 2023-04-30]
stl/STLinkPlug.stl
15.0 x 10.0 x 4.00

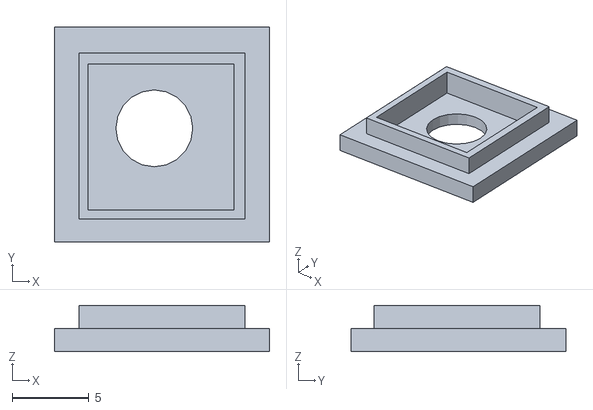
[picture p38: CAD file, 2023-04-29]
stl/ButtonCover.stl
14.0 x 14.0 x 3.00

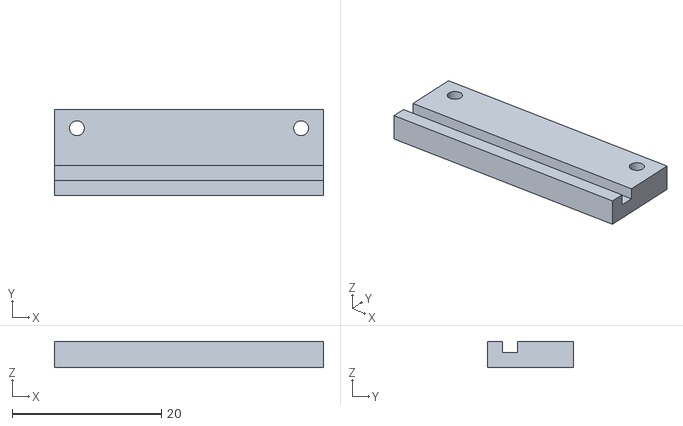
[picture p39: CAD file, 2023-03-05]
stl/STM32-PCM5102ABox6Clamp.stl
36.0 x 11.5 x 3.50

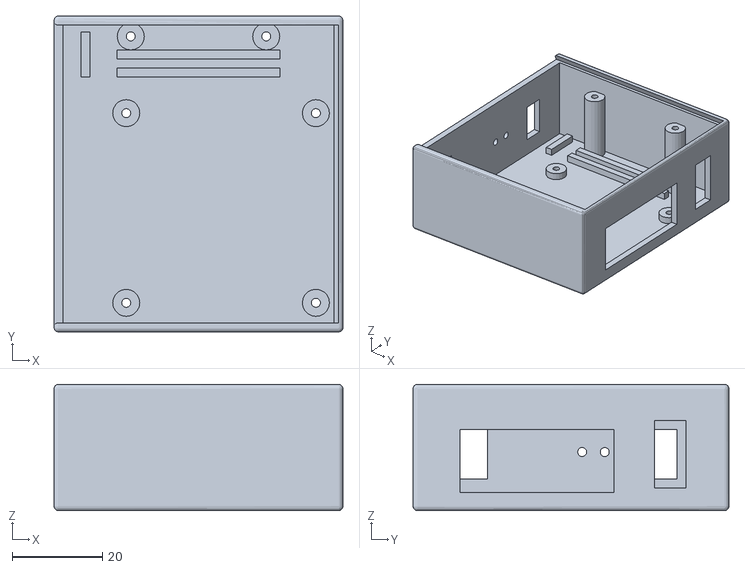
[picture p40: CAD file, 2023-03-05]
stl/STM32-PCM5102ABox6.stl
64.0 x 70.0 x 28.0

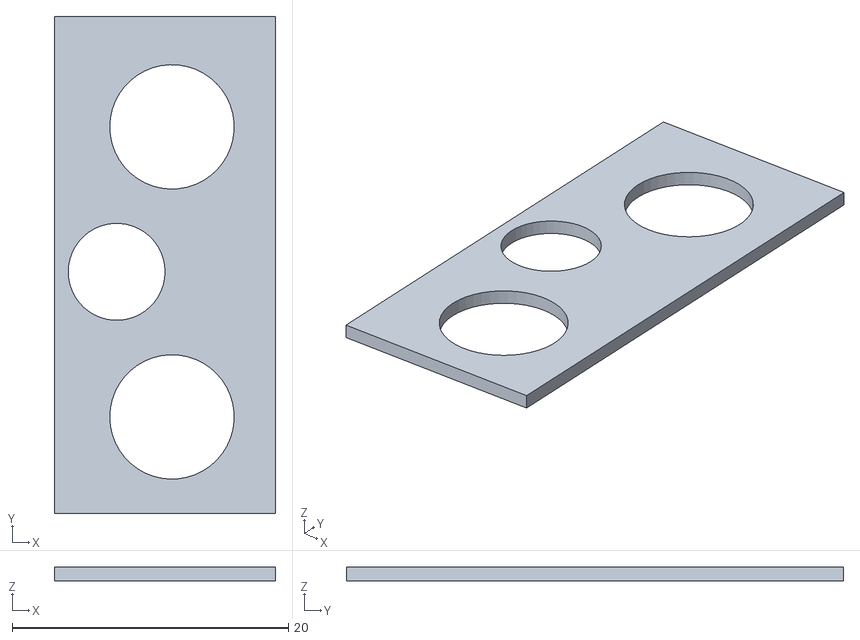
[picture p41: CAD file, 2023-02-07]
stl/Coverplate1PCM5102ABox4.stl
16.0 x 36.0 x 1.00

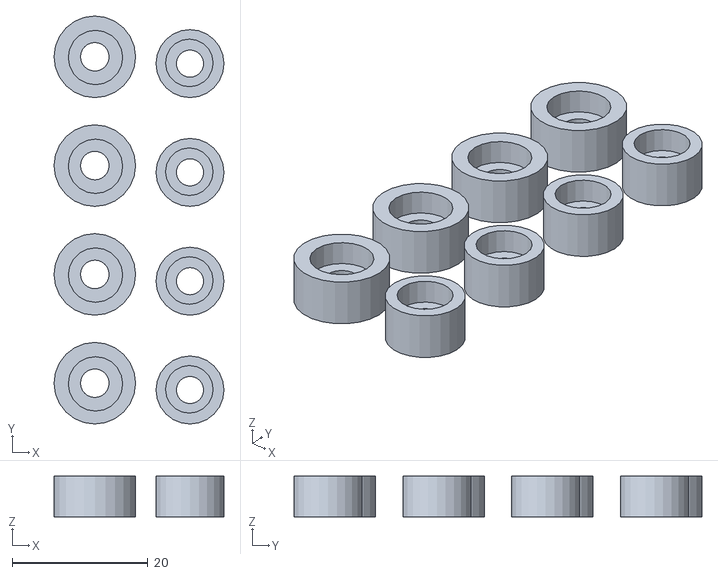
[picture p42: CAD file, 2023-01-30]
stl/ChassisFeet3.stl
25.0 x 60.0 x 6.00

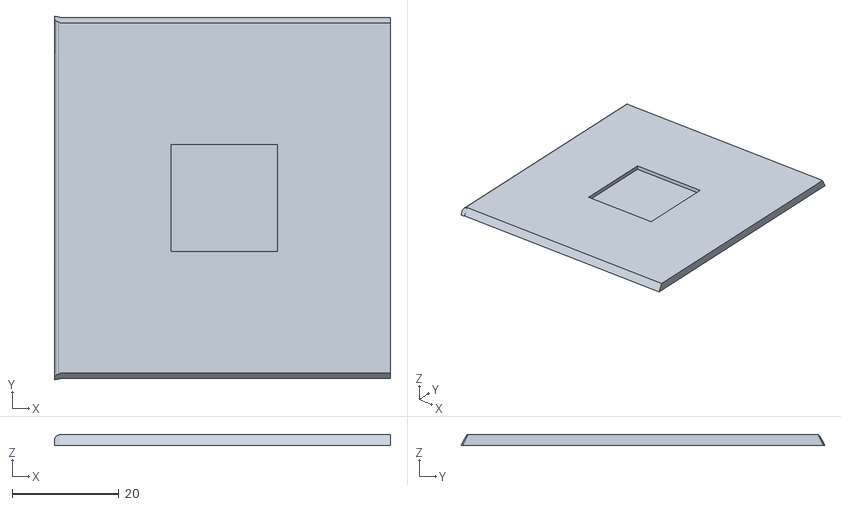
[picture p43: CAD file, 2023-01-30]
stl/STM32-PCM5102ALid4.stl
63.0 x 68.2 x 2.00

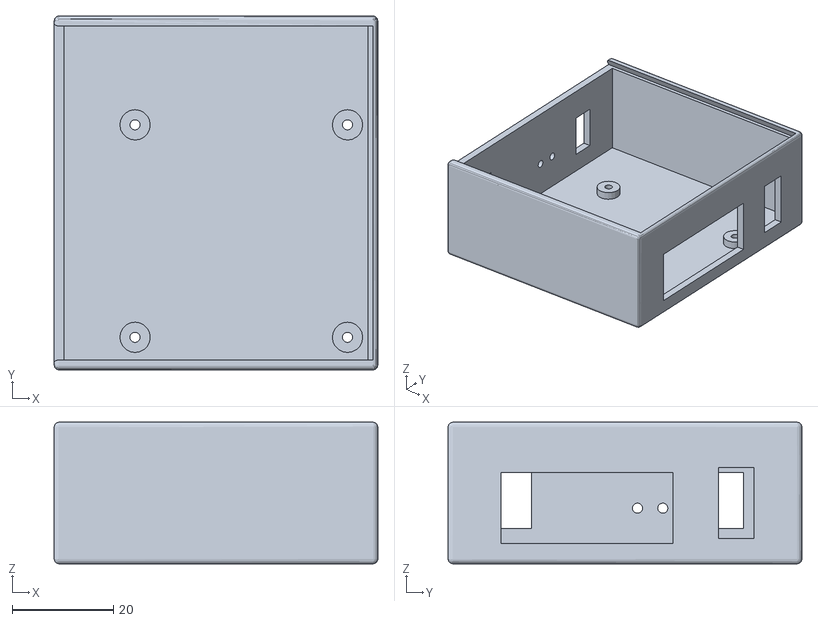
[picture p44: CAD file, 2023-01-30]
stl/STM32-PCM5102ABox4.stl
64.0 x 70.0 x 28.0

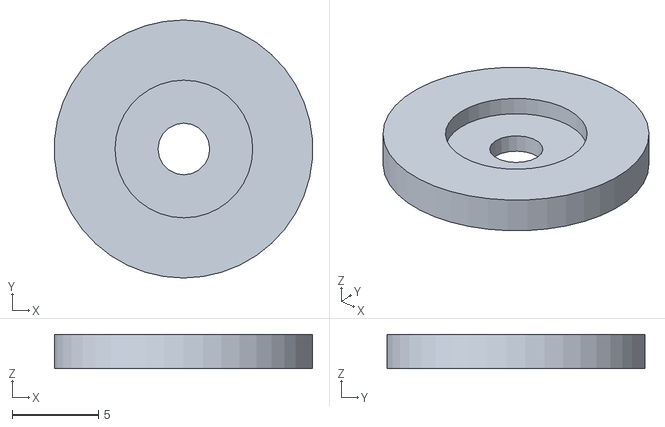
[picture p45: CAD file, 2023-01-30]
stl/NutWasher1.stl
15.0 x 15.0 x 2.00

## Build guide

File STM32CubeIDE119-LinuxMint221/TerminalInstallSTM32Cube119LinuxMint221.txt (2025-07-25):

sudo sh ./st-stm32cubeide_1.19.0_25607_20250703_0907_amd64.deb_bundle.sh

I ACCEPT (y) / I DO NOT ACCEPT (N) [N/y] y
License accepted.
Reading package lists... Done
Building dependency tree... Done
Reading state information... Done
Note, selecting 'st-stlink-server' instead of './st-stlink-server-2.1.1-1-linux-amd64.deb'
Note, selecting 'st-stlink-udev-rules' instead of './st-stlink-udev-rules-1.0.3-2-linux-all.deb'
Note, selecting 'st-stm32cubeide-1.19.0' instead of './st-stm32cubeide-1.19.0-25607-20250703-0907_amd64.deb'
Note, selecting 'segger-jlink-udev-rules' instead of './segger-jlink-udev-rules-8.38_fixed-linux-all.deb'
Recommended packages:
  libncurses5 libpython2.7 libwebkit2gtk-4.0-37
The following NEW packages will be installed:
  segger-jlink-udev-rules st-stlink-server st-stlink-udev-rules st-stm32cubeide-1.19.0
0 upgraded, 4 newly installed, 0 to remove and 167 not upgraded.
Need to get 0 B/1,139 MB of archives.
After this operation, 0 B of additional disk space will be used.
Get:1 /home/tobias/Downloads/makeself_dir_4jAoyg/segger-jlink-udev-rules-8.38_fixed-linux-all.deb segger-jlink-udev-rules all 8.38-fixed [18.2 kB]
Get:2 /home/tobias/Downloads/makeself_dir_4jAoyg/st-stlink-server-2.1.1-1-linux-amd64.deb st-stlink-server amd64 2.1.1-1 [51.8 kB]
Get:3 /home/tobias/Downloads/makeself_dir_4jAoyg/st-stlink-udev-rules-1.0.3-2-linux-all.deb st-stlink-udev-rules all 1.0.3-2 [4,880 B]
Get:4 /home/tobias/Downloads/makeself_dir_4jAoyg/st-stm32cubeide-1.19.0-25607-20250703-0907_amd64.deb st-stm32cubeide-1.19.0 amd64 1.19.0-25607-20250703-0907-1 [1,139 MB]
Selecting previously unselected package segger-jlink-udev-rules.
(Reading database ... 463745 files and directories currently installed.)
Preparing to unpack .../segger-jlink-udev-rules-8.38_fixed-linux-all.deb ...
Unpacking segger-jlink-udev-rules (8.38-fixed) ...
Selecting previously unselected package st-stlink-server.
Preparing to unpack .../st-stlink-server-2.1.1-1-linux-amd64.deb ...
Stopping stlink-server (if any)...
Unpacking st-stlink-server (2.1.1-1) ...
Selecting previously unselected package st-stlink-udev-rules.
Preparing to unpack .../st-stlink-udev-rules-1.0.3-2-linux-all.deb ...
Unpacking st-stlink-udev-rules (1.0.3-2) ...
Selecting previously unselected package st-stm32cubeide-1.19.0.
Preparing to unpack .../st-stm32cubeide-1.19.0-25607-20250703-0907_amd64.deb ...
Unpacking st-stm32cubeide-1.19.0 (1.19.0-25607-20250703-0907-1) ...
Setting up segger-jlink-udev-rules (8.38-fixed) ...
Setting up st-stlink-udev-rules (1.0.3-2) ...
Setting up st-stlink-server (2.1.1-1) ...
Setting up st-stm32cubeide-1.19.0 (1.19.0-25607-20250703-0907-1) ...
Processing triggers for desktop-file-utils (0.27-2build1) ...
Processing triggers for gnome-menus (3.36.0-1.1ubuntu3) ...
Processing triggers for mate-menus (1.26.1+mint1) ...
Processing triggers for mailcap (3.70+nmu1ubuntu1) ...
N: Download is performed unsandboxed as root as file '/home/tobias/Downloads/makeself_dir_4jAoyg/segger-jlink-udev-rules-8.38_fixed-linux-all.deb' couldn't be accessed by user '_apt'. - pkgAcquire::Run (13: Permission denied)
STM32CubeIDE installed successfully

sudo apt install ./stlink_1.8.0-1_amd64.deb

tobias@pc14400:~/Downloads$ sudo apt install ./stlink_1.8.0-1_amd64.deb
Reading package lists... Done
Building dependency tree... Done
Reading state information... Done
Note, selecting 'stlink' instead of './stlink_1.8.0-1_amd64.deb'
The following additional packages will be installed:
  autoconf automake autopoint autotools-dev cmake cmake-data debhelper debugedit dh-autoreconf dh-strip-nondeterminism dwz intltool-debian libarchive-cpio-perl
  libarchive-zip-perl libdebhelper-perl libfile-stripnondeterminism-perl libjsoncpp25 libltdl-dev libmail-sendmail-perl librhash0 libsub-override-perl
  libsys-hostname-long-perl libtool libusb-1.0-0-dev libusb-1.0-doc m4 po-debconf
Suggested packages:
  autoconf-archive gnu-standards autoconf-doc cmake-doc cmake-format elpa-cmake-mode ninja-build dh-make libtool-doc gfortran | fortran95-compiler gcj-jdk m4-doc
  libmail-box-perl libgtk-3-dev pandoc
The following NEW packages will be installed:
  autoconf automake autopoint autotools-dev cmake cmake-data debhelper debugedit dh-autoreconf dh-strip-nondeterminism dwz intltool-debian libarchive-cpio-perl
  libarchive-zip-perl libdebhelper-perl libfile-stripnondeterminism-perl libjsoncpp25 libltdl-dev libmail-sendmail-perl librhash0 libsub-override-perl
  libsys-hostname-long-perl libtool libusb-1.0-0-dev libusb-1.0-doc m4 po-debconf stlink
0 upgraded, 28 newly installed, 0 to remove and 167 not upgraded.
Need to get 17.3 MB/17.5 MB of archives.
After this operation, 62.7 MB of additional disk space will be used.
Do you want to continue? [Y/n] y
Get:1 /home/tobias/Downloads/stlink_1.8.0-1_amd64.deb stlink amd64 1.8.0-1 [210 kB]
Get:2 http://archive.ubuntu.com/ubuntu noble/main amd64 m4 amd64 1.4.19-4build1 [244 kB]
Get:3 http://archive.ubuntu.com/ubuntu noble/main amd64 autoconf all 2.71-3 [339 kB]
Get:4 http://archive.ubuntu.com/ubuntu noble/main amd64 autotools-dev all 20220109.1 [44.9 kB]
Get:5 http://archive.ubuntu.com/ubuntu noble/main amd64 automake all 1:1.16.5-1.3ubuntu1 [558 kB]
Get:6 http://archive.ubuntu.com/ubuntu noble/main amd64 autopoint all 0.21-14ubuntu2 [422 kB]
Get:7 http://archive.ubuntu.com/ubuntu noble/main amd64 libjsoncpp25 amd64 1.9.5-6build1 [82.8 kB]
Get:8 http://archive.ubuntu.com/ubuntu noble/main amd64 librhash0 amd64 1.4.3-3build1 [129 kB]
Get:9 http://archive.ubuntu.com/ubuntu noble/main amd64 cmake-data all 3.28.3-1build7 [2,155 kB]
Get:10 http://archive.ubuntu.com/ubuntu noble/main amd64 cmake amd64 3.28.3-1build7 [11.2 MB]
Get:11 http://archive.ubuntu.com/ubuntu noble/main amd64 libdebhelper-perl all 13.14.1ubuntu5 [89.8 kB]
Get:12 http://archive.ubuntu.com/ubuntu noble/main amd64 libtool all 2.4.7-7build1 [166 kB]                                                                              
Get:13 http://archive.ubuntu.com/ubuntu noble/main amd64 dh-autoreconf all 20 [16.1 kB]                                                                                  
Get:14 http://archive.ubuntu.com/ubuntu noble/main amd64 libarchive-zip-perl all 1.68-1 [90.2 kB]                                                                        
Get:15 http://archive.ubuntu.com/ubuntu noble/main amd64 libsub-override-perl all 0.10-1 [10.0 kB]                                                                       
Get:16 http://archive.ubuntu.com/ubuntu noble/main amd64 libfile-stripnondeterminism-perl all 1.13.1-1 [18.1 kB]                                                         
Get:17 http://archive.ubuntu.com/ubuntu noble/main amd64 dh-strip-nondeterminism all 1.13.1-1 [5,362 B]                                                                  
Get:18 http://archive.ubuntu.com/ubuntu noble/main amd64 debugedit amd64 1:5.0-5build2 [46.1 kB]                                                                         
Get:19 http://archive.ubuntu.com/ubuntu noble/main amd64 dwz amd64 0.15-1build6 [115 kB]                                                                                 
Get:20 http://archive.ubuntu.com/ubuntu noble/main amd64 intltool-debian all 0.35.0+20060710.6 [23.2 kB]                                                                 
Get:21 http://archive.ubuntu.com/ubuntu noble/main amd64 po-debconf all 1.0.21+nmu1 [233 kB]                                                                             
Get:22 http://archive.ubuntu.com/ubuntu noble/main amd64 debhelper all 13.14.1ubuntu5 [869 kB]                                                                           
Get:23 http://archive.ubuntu.com/ubuntu noble/main amd64 libarchive-cpio-perl all 0.10-3 [10.3 kB]                                                                       
Get:24 http://archive.ubuntu.com/ubuntu noble/main amd64 libltdl-dev amd64 2.4.7-7build1 [168 kB]                                                                        
Get:25 http://archive.ubuntu.com/ubuntu noble/main amd64 libsys-hostname-long-perl all 1.5-3 [10.6 kB]                                                                   
Get:26 http://archive.ubuntu.com/ubuntu noble/main amd64 libmail-sendmail-perl all 0.80-3 [21.7 kB]                                                                      
Get:27 http://archive.ubuntu.com/ubuntu noble/main amd64 libusb-1.0-0-dev amd64 2:1.0.27-1 [77.7 kB]                                                                     
Get:28 http://archive.ubuntu.com/ubuntu noble/main amd64 libusb-1.0-doc all 2:1.0.27-1 [199 kB]                                                                          
Fetched 17.3 MB in 9s (1,948 kB/s)                                                                                                                                       
Selecting previously unselected package m4.
(Reading database ... 485929 files and directories currently installed.)
Preparing to unpack .../00-m4_1.4.19-4build1_amd64.deb ...
Unpacking m4 (1.4.19-4build1) ...
Selecting previously unselected package autoconf.
Preparing to unpack .../01-autoconf_2.71-3_all.deb ...
Unpacking autoconf (2.71-3) ...
Selecting previously unselected package autotools-dev.
Preparing to unpack .../02-autotools-dev_20220109.1_all.deb ...
Unpacking autotools-dev (20220109.1) ...
Selecting previously unselected package automake.
Preparing to unpack .../03-automake_1%3a1.16.5-1.3ubuntu1_all.deb ...
Unpacking automake (1:1.16.5-1.3ubuntu1) ...
Selecting previously unselected package autopoint.
Preparing to unpack .../04-autopoint_0.21-14ubuntu2_all.deb ...
Unpacking autopoint (0.21-14ubuntu2) ...
Selecting previously unselected package libjsoncpp25:amd64.
Preparing to unpack .../05-libjsoncpp25_1.9.5-6build1_amd64.deb ...
Unpacking libjsoncpp25:amd64 (1.9.5-6build1) ...
Selecting previously unselected package librhash0:amd64.
Preparing to unpack .../06-librhash0_1.4.3-3build1_amd64.deb ...
Unpacking librhash0:amd64 (1.4.3-3build1) ...
Selecting previously unselected package cmake-data.
Preparing to unpack .../07-cmake-data_3.28.3-1build7_all.deb ...
Unpacking cmake-data (3.28.3-1build7) ...
Selecting previously unselected package cmake.
Preparing to unpack .../08-cmake_3.28.3-1build7_amd64.deb ...
Unpacking cmake (3.28.3-1build7) ...
Selecting previously unselected package libdebhelper-perl.
Preparing to unpack .../09-libdebhelper-perl_13.14.1ubuntu5_all.deb ...
Unpacking libdebhelper-perl (13.14.1ubuntu5) ...
Selecting previously unselected package libtool.
Preparing to unpack .../10-libtool_2.4.7-7build1_all.deb ...
Unpacking libtool (2.4.7-7build1) ...
Selecting previously unselected package dh-autoreconf.
Preparing to unpack .../11-dh-autoreconf_20_all.deb ...
Unpacking dh-autoreconf (20) ...
Selecting previously unselected package libarchive-zip-perl.
Preparing to unpack .../12-libarchive-zip-perl_1.68-1_all.deb ...
Unpacking libarchive-zip-perl (1.68-1) ...
Selecting previously unselected package libsub-override-perl.
Preparing to unpack .../13-libsub-override-perl_0.10-1_all.deb ...
Unpacking libsub-override-perl (0.10-1) ...
Selecting previously unselected package libfile-stripnondeterminism-perl.
Preparing to unpack .../14-libfile-stripnondeterminism-perl_1.13.1-1_all.deb ...
Unpacking libfile-stripnondeterminism-perl (1.13.1-1) ...
Selecting previously unselected package dh-strip-nondeterminism.
Preparing to unpack .../15-dh-strip-nondeterminism_1.13.1-1_all.deb ...
Unpacking dh-strip-nondeterminism (1.13.1-1) ...
Selecting previously unselected package debugedit.
Preparing to unpack .../16-debugedit_1%3a5.0-5build2_amd64.deb ...
Unpacking debugedit (1:5.0-5build2) ...
Selecting previously unselected package dwz.
Preparing to unpack .../17-dwz_0.15-1build6_amd64.deb ...
Unpacking dwz (0.15-1build6) ...
Selecting previously unselected package intltool-debian.
Preparing to unpack .../18-intltool-debian_0.35.0+20060710.6_all.deb ...
Unpacking intltool-debian (0.35.0+20060710.6) ...
Selecting previously unselected package po-debconf.
Preparing to unpack .../19-po-debconf_1.0.21+nmu1_all.deb ...
Unpacking po-debconf (1.0.21+nmu1) ...
Selecting previously unselected package debhelper.
Preparing to unpack .../20-debhelper_13.14.1ubuntu5_all.deb ...
Unpacking debhelper (13.14.1ubuntu5) ...
Selecting previously unselected package libarchive-cpio-perl.
Preparing to unpack .../21-libarchive-cpio-perl_0.10-3_all.deb ...
Unpacking libarchive-cpio-perl (0.10-3) ...
Selecting previously unselected package libltdl-dev:amd64.
Preparing to unpack .../22-libltdl-dev_2.4.7-7build1_amd64.deb ...
Unpacking libltdl-dev:amd64 (2.4.7-7build1) ...
Selecting previously unselected package libsys-hostname-long-perl.
Preparing to unpack .../23-libsys-hostname-long-perl_1.5-3_all.deb ...
Unpacking libsys-hostname-long-perl (1.5-3) ...
Selecting previously unselected package libmail-sendmail-perl.
Preparing to unpack .../24-libmail-sendmail-perl_0.80-3_all.deb ...
Unpacking libmail-sendmail-perl (0.80-3) ...
Selecting previously unselected package libusb-1.0-0-dev:amd64.
Preparing to unpack .../25-libusb-1.0-0-dev_2%3a1.0.27-1_amd64.deb ...
Unpacking libusb-1.0-0-dev:amd64 (2:1.0.27-1) ...
Selecting previously unselected package libusb-1.0-doc.
Preparing to unpack .../26-libusb-1.0-doc_2%3a1.0.27-1_all.deb ...
Unpacking libusb-1.0-doc (2:1.0.27-1) ...
Selecting previously unselected package stlink.
Preparing to unpack .../27-stlink_1.8.0-1_amd64.deb ...
Unpacking stlink (1.8.0-1) ...
Setting up libarchive-zip-perl (1.68-1) ...
Setting up libdebhelper-perl (13.14.1ubuntu5) ...
Setting up libusb-1.0-doc (2:1.0.27-1) ...
Setting up libusb-1.0-0-dev:amd64 (2:1.0.27-1) ...
Setting up m4 (1.4.19-4build1) ...
Setting up intltool-debian (0.35.0+20060710.6) ...
Setting up autotools-dev (20220109.1) ...
Setting up autopoint (0.21-14ubuntu2) ...
Setting up libjsoncpp25:amd64 (1.9.5-6build1) ...
Setting up autoconf (2.71-3) ...
Setting up dwz (0.15-1build6) ...
Setting up librhash0:amd64 (1.4.3-3build1) ...
Setting up libarchive-cpio-perl (0.10-3) ...
Setting up debugedit (1:5.0-5build2) ...
Setting up libsub-override-perl (0.10-1) ...
Setting up cmake-data (3.28.3-1build7) ...
Setting up libsys-hostname-long-perl (1.5-3) ...
Setting up automake (1:1.16.5-1.3ubuntu1) ...
update-alternatives: using /usr/bin/automake-1.16 to provide /usr/bin/automake (automake) in auto mode
Setting up libfile-stripnondeterminism-perl (1.13.1-1) ...
Setting up libtool (2.4.7-7build1) ...
Setting up po-debconf (1.0.21+nmu1) ...
Setting up dh-autoreconf (20) ...
Setting up libmail-sendmail-perl (0.80-3) ...
Setting up libltdl-dev:amd64 (2.4.7-7build1) ...
Setting up dh-strip-nondeterminism (1.13.1-1) ...
Setting up cmake (3.28.3-1build7) ...
Setting up debhelper (13.14.1ubuntu5) ...
Setting up stlink (1.8.0-1) ...
Processing triggers for install-info (7.1-3build2) ...
Processing triggers for libc-bin (2.39-0ubuntu8.4) ...
Processing triggers for man-db (2.12.0-4build2) ...
N: Download is performed unsandboxed as root as file '/home/tobias/Downloads/stlink_1.8.0-1_amd64.deb' couldn't be accessed by user '_apt'. - pkgAcquire::Run (13: Permission denied)

tobias@pc14400:~/Downloads/STM32F411_USB_AUDIO_DAC-main$ export PATH=$PATH:/opt/st/stm32cubeide_1.19.0/plugins//opt/st/stm32cubeide_1.19.0/plugins/com.st.stm32cube.ide.mcu.externaltools.make.linux64_2.2.0.202409170845/tools/bin
tobias@pc14400:~/Downloads/STM32F411_USB_AUDIO_DAC-main$ export PATH=$PATH:/opt/st/stm32cubeide_1.19.0/plugins/com.st.stm32cube.ide.mcu.externaltools.gnu-tools-for-stm32.13.3.rel1.linux64_1.0.0.202410170706/tools/bin
tobias@pc14400:~/Downloads/STM32F411_USB_AUDIO_DAC-main$ 

tobias@pc14400:~/Downloads/STM32F411_USB_AUDIO_DAC-main$ make clean
rm -fR ./build
tobias@pc14400:~/Downloads/STM32F411_USB_AUDIO_DAC-main$ make
mkdir build		
arm-none-eabi-gcc -c -mcpu=cortex-m4 -mthumb -mfpu=fpv4-sp-d16 -mfloat-abi=hard -DUSE_HAL_DRIVER -DUSE_FULL_ASSERT -DSTM32F411xE -DDAC_PCM5102A -Isrc -Idrivers/BSP -Idrivers/usb/Core/Inc -Idrivers/usb/Class/AUDIO/Inc -Idrivers/CMSIS/Device/ST/STM32F4xx/Include -Idrivers/CMSIS/Include -Idrivers/STM32F4xx_HAL_Driver/Inc -Idrivers/STM32F4xx_HAL_Driver/Inc/Legacy -O2 -Wall -fdata-sections -ffunction-sections -MMD -MP -MF"build/main.d" -Wa,-a,-ad,-alms=./build/main.lst src/main.c -o build/main.o
arm-none-eabi-gcc -c -mcpu=cortex-m4 -mthumb -mfpu=fpv4-sp-d16 -mfloat-abi=hard -DUSE_HAL_DRIVER -DUSE_FULL_ASSERT -DSTM32F411xE -DDAC_PCM5102A -Isrc -Idrivers/BSP -Idrivers/usb/Core/Inc -Idrivers/usb/Class/AUDIO/Inc -Idrivers/CMSIS/Device/ST/STM32F4xx/Include -Idrivers/CMSIS/Include -Idrivers/STM32F4xx_HAL_Driver/Inc -Idrivers/STM32F4xx_HAL_Driver/Inc/Legacy -O2 -Wall -fdata-sections -ffunction-sections -MMD -MP -MF"build/usart.d" -Wa,-a,-ad,-alms=./build/usart.lst src/usart.c -o build/usart.o
arm-none-eabi-gcc -c -mcpu=cortex-m4 -mthumb -mfpu=fpv4-sp-d16 -mfloat-abi=hard -DUSE_HAL_DRIVER -DUSE_FULL_ASSERT -DSTM32F411xE -DDAC_PCM5102A -Isrc -Idrivers/BSP -Idrivers/usb/Core/Inc -Idrivers/usb/Class/AUDIO/Inc -Idrivers/CMSIS/Device/ST/STM32F4xx/Include -Idrivers/CMSIS/Include -Idrivers/STM32F4xx_HAL_Driver/Inc -Idrivers/STM32F4xx_HAL_Driver/Inc/Legacy -O2 -Wall -fdata-sections -ffunction-sections -MMD -MP -MF"build/usbd_conf.d" -Wa,-a,-ad,-alms=./build/usbd_conf.lst src/usbd_conf.c -o build/usbd_conf.o
arm-none-eabi-gcc -c -mcpu=cortex-m4 -mthumb -mfpu=fpv4-sp-d16 -mfloat-abi=hard -DUSE_HAL_DRIVER -DUSE_FULL_ASSERT -DSTM32F411xE -DDAC_PCM5102A -Isrc -Idrivers/BSP -Idrivers/usb/Core/Inc -Idrivers/usb/Class/AUDIO/Inc -Idrivers/CMSIS/Device/ST/STM32F4xx/Include -Idrivers/CMSIS/Include -Idrivers/STM32F4xx_HAL_Driver/Inc -Idrivers/STM32F4xx_HAL_Driver/Inc/Legacy -O2 -Wall -fdata-sections -ffunction-sections -MMD -MP -MF"build/usbd_desc.d" -Wa,-a,-ad,-alms=./build/usbd_desc.lst src/usbd_desc.c -o build/usbd_desc.o
arm-none-eabi-gcc -c -mcpu=cortex-m4 -mthumb -mfpu=fpv4-sp-d16 -mfloat-abi=hard -DUSE_HAL_DRIVER -DUSE_FULL_ASSERT -DSTM32F411xE -DDAC_PCM5102A -Isrc -Idrivers/BSP -Idrivers/usb/Core/Inc -Idrivers/usb/Class/AUDIO/Inc -Idrivers/CMSIS/Device/ST/STM32F4xx/Include -Idrivers/CMSIS/Include -Idrivers/STM32F4xx_HAL_Driver/Inc -Idrivers/STM32F4xx_HAL_Driver/Inc/Legacy -O2 -Wall -fdata-sections -ffunction-sections -MMD -MP -MF"build/usbd_audio_if.d" -Wa,-a,-ad,-alms=./build/usbd_audio_if.lst src/usbd_audio_if.c -o build/usbd_audio_if.o
arm-none-eabi-gcc -c -mcpu=cortex-m4 -mthumb -mfpu=fpv4-sp-d16 -mfloat-abi=hard -DUSE_HAL_DRIVER -DUSE_FULL_ASSERT -DSTM32F411xE -DDAC_PCM5102A -Isrc -Idrivers/BSP -Idrivers/usb/Core/Inc -Idrivers/usb/Class/AUDIO/Inc -Idrivers/CMSIS/Device/ST/STM32F4xx/Include -Idrivers/CMSIS/Include -Idrivers/STM32F4xx_HAL_Driver/Inc -Idrivers/STM32F4xx_HAL_Driver/Inc/Legacy -O2 -Wall -fdata-sections -ffunction-sections -MMD -MP -MF"build/stm32f4xx_it.d" -Wa,-a,-ad,-alms=./build/stm32f4xx_it.lst src/stm32f4xx_it.c -o build/stm32f4xx_it.o
arm-none-eabi-gcc -c -mcpu=cortex-m4 -mthumb -mfpu=fpv4-sp-d16 -mfloat-abi=hard -DUSE_HAL_DRIVER -DUSE_FULL_ASSERT -DSTM32F411xE -DDAC_PCM5102A -Isrc -Idrivers/BSP -Idrivers/usb/Core/Inc -Idrivers/usb/Class/AUDIO/Inc -Idrivers/CMSIS/Device/ST/STM32F4xx/Include -Idrivers/CMSIS/Include -Idrivers/STM32F4xx_HAL_Driver/Inc -Idrivers/STM32F4xx_HAL_Driver/Inc/Legacy -O2 -Wall -fdata-sections -ffunction-sections -MMD -MP -MF"build/system_stm32f4xx.d" -Wa,-a,-ad,-alms=./build/system_stm32f4xx.lst src/system_stm32f4xx.c -o build/system_stm32f4xx.o
arm-none-eabi-gcc -c -mcpu=cortex-m4 -mthumb -mfpu=fpv4-sp-d16 -mfloat-abi=hard -DUSE_HAL_DRIVER -DUSE_FULL_ASSERT -DSTM32F411xE -DDAC_PCM5102A -Isrc -Idrivers/BSP -Idrivers/usb/Core/Inc -Idrivers/usb/Class/AUDIO/Inc -Idrivers/CMSIS/Device/ST/STM32F4xx/Include -Idrivers/CMSIS/Include -Idrivers/STM32F4xx_HAL_Driver/Inc -Idrivers/STM32F4xx_HAL_Driver/Inc/Legacy -O2 -Wall -fdata-sections -ffunction-sections -MMD -MP -MF"build/usbd_core.d" -Wa,-a,-ad,-alms=./build/usbd_core.lst drivers/usb/Core/Src/usbd_core.c -o build/usbd_core.o
arm-none-eabi-gcc -c -mcpu=cortex-m4 -mthumb -mfpu=fpv4-sp-d16 -mfloat-abi=hard -DUSE_HAL_DRIVER -DUSE_FULL_ASSERT -DSTM32F411xE -DDAC_PCM5102A -Isrc -Idrivers/BSP -Idrivers/usb/Core/Inc -Idrivers/usb/Class/AUDIO/Inc -Idrivers/CMSIS/Device/ST/STM32F4xx/Include -Idrivers/CMSIS/Include -Idrivers/STM32F4xx_HAL_Driver/Inc -Idrivers/STM32F4xx_HAL_Driver/Inc/Legacy -O2 -Wall -fdata-sections -ffunction-sections -MMD -MP -MF"build/usbd_ctlreq.d" -Wa,-a,-ad,-alms=./build/usbd_ctlreq.lst drivers/usb/Core/Src/usbd_ctlreq.c -o build/usbd_ctlreq.o
arm-none-eabi-gcc -c -mcpu=cortex-m4 -mthumb -mfpu=fpv4-sp-d16 -mfloat-abi=hard -DUSE_HAL_DRIVER -DUSE_FULL_ASSERT -DSTM32F411xE -DDAC_PCM5102A -Isrc -Idrivers/BSP -Idrivers/usb/Core/Inc -Idrivers/usb/Class/AUDIO/Inc -Idrivers/CMSIS/Device/ST/STM32F4xx/Include -Idrivers/CMSIS/Include -Idrivers/STM32F4xx_HAL_Driver/Inc -Idrivers/STM32F4xx_HAL_Driver/Inc/Legacy -O2 -Wall -fdata-sections -ffunction-sections -MMD -MP -MF"build/usbd_ioreq.d" -Wa,-a,-ad,-alms=./build/usbd_ioreq.lst drivers/usb/Core/Src/usbd_ioreq.c -o build/usbd_ioreq.o
arm-none-eabi-gcc -c -mcpu=cortex-m4 -mthumb -mfpu=fpv4-sp-d16 -mfloat-abi=hard -DUSE_HAL_DRIVER -DUSE_FULL_ASSERT -DSTM32F411xE -DDAC_PCM5102A -Isrc -Idrivers/BSP -Idrivers/usb/Core/Inc -Idrivers/usb/Class/AUDIO/Inc -Idrivers/CMSIS/Device/ST/STM32F4xx/Include -Idrivers/CMSIS/Include -Idrivers/STM32F4xx_HAL_Driver/Inc -Idrivers/STM32F4xx_HAL_Driver/Inc/Legacy -O2 -Wall -fdata-sections -ffunction-sections -MMD -MP -MF"build/usbd_audio.d" -Wa,-a,-ad,-alms=./build/usbd_audio.lst drivers/usb/Class/AUDIO/Src/usbd_audio.c -o build/usbd_audio.o
arm-none-eabi-gcc -c -mcpu=cortex-m4 -mthumb -mfpu=fpv4-sp-d16 -mfloat-abi=hard -DUSE_HAL_DRIVER -DUSE_FULL_ASSERT -DSTM32F411xE -DDAC_PCM5102A -Isrc -Idrivers/BSP -Idrivers/usb/Core/Inc -Idrivers/usb/Class/AUDIO/Inc -Idrivers/CMSIS/Device/ST/STM32F4xx/Include -Idrivers/CMSIS/Include -Idrivers/STM32F4xx_HAL_Driver/Inc -Idrivers/STM32F4xx_HAL_Driver/Inc/Legacy -O2 -Wall -fdata-sections -ffunction-sections -MMD -MP -MF"build/bsp_misc.d" -Wa,-a,-ad,-alms=./build/bsp_misc.lst drivers/BSP/bsp_misc.c -o build/bsp_misc.o
arm-none-eabi-gcc -c -mcpu=cortex-m4 -mthumb -mfpu=fpv4-sp-d16 -mfloat-abi=hard -DUSE_HAL_DRIVER -DUSE_FULL_ASSERT -DSTM32F411xE -DDAC_PCM5102A -Isrc -Idrivers/BSP -Idrivers/usb/Core/Inc -Idrivers/usb/Class/AUDIO/Inc -Idrivers/CMSIS/Device/ST/STM32F4xx/Include -Idrivers/CMSIS/Include -Idrivers/STM32F4xx_HAL_Driver/Inc -Idrivers/STM32F4xx_HAL_Driver/Inc/Legacy -O2 -Wall -fdata-sections -ffunction-sections -MMD -MP -MF"build/bsp_audio.d" -Wa,-a,-ad,-alms=./build/bsp_audio.lst drivers/BSP/bsp_audio.c -o build/bsp_audio.o
arm-none-eabi-gcc -c -mcpu=cortex-m4 -mthumb -mfpu=fpv4-sp-d16 -mfloat-abi=hard -DUSE_HAL_DRIVER -DUSE_FULL_ASSERT -DSTM32F411xE -DDAC_PCM5102A -Isrc -Idrivers/BSP -Idrivers/usb/Core/Inc -Idrivers/usb/Class/AUDIO/Inc -Idrivers/CMSIS/Device/ST/STM32F4xx/Include -Idrivers/CMSIS/Include -Idrivers/STM32F4xx_HAL_Driver/Inc -Idrivers/STM32F4xx_HAL_Driver/Inc/Legacy -O2 -Wall -fdata-sections -ffunction-sections -MMD -MP -MF"build/stm32f4xx_hal_pcd.d" -Wa,-a,-ad,-alms=./build/stm32f4xx_hal_pcd.lst drivers/STM32F4xx_HAL_Driver/Src/stm32f4xx_hal_pcd.c -o build/stm32f4xx_hal_pcd.o
arm-none-eabi-gcc -c -mcpu=cortex-m4 -mthumb -mfpu=fpv4-sp-d16 -mfloat-abi=hard -DUSE_HAL_DRIVER -DUSE_FULL_ASSERT -DSTM32F411xE -DDAC_PCM5102A -Isrc -Idrivers/BSP -Idrivers/usb/Core/Inc -Idrivers/usb/Class/AUDIO/Inc -Idrivers/CMSIS/Device/ST/STM32F4xx/Include -Idrivers/CMSIS/Include -Idrivers/STM32F4xx_HAL_Driver/Inc -Idrivers/STM32F4xx_HAL_Driver/Inc/Legacy -O2 -Wall -fdata-sections -ffunction-sections -MMD -MP -MF"build/stm32f4xx_hal_pcd_ex.d" -Wa,-a,-ad,-alms=./build/stm32f4xx_hal_pcd_ex.lst drivers/STM32F4xx_HAL_Driver/Src/stm32f4xx_hal_pcd_ex.c -o build/stm32f4xx_hal_pcd_ex.o
arm-none-eabi-gcc -c -mcpu=cortex-m4 -mthumb -mfpu=fpv4-sp-d16 -mfloat-abi=hard -DUSE_HAL_DRIVER -DUSE_FULL_ASSERT -DSTM32F411xE -DDAC_PCM5102A -Isrc -Idrivers/BSP -Idrivers/usb/Core/Inc -Idrivers/usb/Class/AUDIO/Inc -Idrivers/CMSIS/Device/ST/STM32F4xx/Include -Idrivers/CMSIS/Include -Idrivers/STM32F4xx_HAL_Driver/Inc -Idrivers/STM32F4xx_HAL_Driver/Inc/Legacy -O2 -Wall -fdata-sections -ffunction-sections -MMD -MP -MF"build/stm32f4xx_ll_usb.d" -Wa,-a,-ad,-alms=./build/stm32f4xx_ll_usb.lst drivers/STM32F4xx_HAL_Driver/Src/stm32f4xx_ll_usb.c -o build/stm32f4xx_ll_usb.o
arm-none-eabi-gcc -c -mcpu=cortex-m4 -mthumb -mfpu=fpv4-sp-d16 -mfloat-abi=hard -DUSE_HAL_DRIVER -DUSE_FULL_ASSERT -DSTM32F411xE -DDAC_PCM5102A -Isrc -Idrivers/BSP -Idrivers/usb/Core/Inc -Idrivers/usb/Class/AUDIO/Inc -Idrivers/CMSIS/Device/ST/STM32F4xx/Include -Idrivers/CMSIS/Include -Idrivers/STM32F4xx_HAL_Driver/Inc -Idrivers/STM32F4xx_HAL_Driver/Inc/Legacy -O2 -Wall -fdata-sections -ffunction-sections -MMD -MP -MF"build/stm32f4xx_hal_i2s.d" -Wa,-a,-ad,-alms=./build/stm32f4xx_hal_i2s.lst drivers/STM32F4xx_HAL_Driver/Src/stm32f4xx_hal_i2s.c -o build/stm32f4xx_hal_i2s.o
arm-none-eabi-gcc -c -mcpu=cortex-m4 -mthumb -mfpu=fpv4-sp-d16 -mfloat-abi=hard -DUSE_HAL_DRIVER -DUSE_FULL_ASSERT -DSTM32F411xE -DDAC_PCM5102A -Isrc -Idrivers/BSP -Idrivers/usb/Core/Inc -Idrivers/usb/Class/AUDIO/Inc -Idrivers/CMSIS/Device/ST/STM32F4xx/Include -Idrivers/CMSIS/Include -Idrivers/STM32F4xx_HAL_Driver/Inc -Idrivers/STM32F4xx_HAL_Driver/Inc/Legacy -O2 -Wall -fdata-sections -ffunction-sections -MMD -MP -MF"build/stm32f4xx_hal_i2s_ex.d" -Wa,-a,-ad,-alms=./build/stm32f4xx_hal_i2s_ex.lst drivers/STM32F4xx_HAL_Driver/Src/stm32f4xx_hal_i2s_ex.c -o build/stm32f4xx_hal_i2s_ex.o
arm-none-eabi-gcc -c -mcpu=cortex-m4 -mthumb -mfpu=fpv4-sp-d16 -mfloat-abi=hard -DUSE_HAL_DRIVER -DUSE_FULL_ASSERT -DSTM32F411xE -DDAC_PCM5102A -Isrc -Idrivers/BSP -Idrivers/usb/Core/Inc -Idrivers/usb/Class/AUDIO/Inc -Idrivers/CMSIS/Device/ST/STM32F4xx/Include -Idrivers/CMSIS/Include -Idrivers/STM32F4xx_HAL_Driver/Inc -Idrivers/STM32F4xx_HAL_Driver/Inc/Legacy -O2 -Wall -fdata-sections -ffunction-sections -MMD -MP -MF"build/stm32f4xx_hal_tim.d" -Wa,-a,-ad,-alms=./build/stm32f4xx_hal_tim.lst drivers/STM32F4xx_HAL_Driver/Src/stm32f4xx_hal_tim.c -o build/stm32f4xx_hal_tim.o
arm-none-eabi-gcc -c -mcpu=cortex-m4 -mthumb -mfpu=fpv4-sp-d16 -mfloat-abi=hard -DUSE_HAL_DRIVER -DUSE_FULL_ASSERT -DSTM32F411xE -DDAC_PCM5102A -Isrc -Idrivers/BSP -Idrivers/usb/Core/Inc -Idrivers/usb/Class/AUDIO/Inc -Idrivers/CMSIS/Device/ST/STM32F4xx/Include -Idrivers/CMSIS/Include -Idrivers/STM32F4xx_HAL_Driver/Inc -Idrivers/STM32F4xx_HAL_Driver/Inc/Legacy -O2 -Wall -fdata-sections -ffunction-sections -MMD -MP -MF"build/stm32f4xx_hal_tim_ex.d" -Wa,-a,-ad,-alms=./build/stm32f4xx_hal_tim_ex.lst drivers/STM32F4xx_HAL_Driver/Src/stm32f4xx_hal_tim_ex.c -o build/stm32f4xx_hal_tim_ex.o
arm-none-eabi-gcc -c -mcpu=cortex-m4 -mthumb -mfpu=fpv4-sp-d16 -mfloat-abi=hard -DUSE_HAL_DRIVER -DUSE_FULL_ASSERT -DSTM32F411xE -DDAC_PCM5102A -Isrc -Idrivers/BSP -Idrivers/usb/Core/Inc -Idrivers/usb/Class/AUDIO/Inc -Idrivers/CMSIS/Device/ST/STM32F4xx/Include -Idrivers/CMSIS/Include -Idrivers/STM32F4xx_HAL_Driver/Inc -Idrivers/STM32F4xx_HAL_Driver/Inc/Legacy -O2 -Wall -fdata-sections -ffunction-sections -MMD -MP -MF"build/stm32f4xx_hal_rcc.d" -Wa,-a,-ad,-alms=./build/stm32f4xx_hal_rcc.lst drivers/STM32F4xx_HAL_Driver/Src/stm32f4xx_hal_rcc.c -o build/stm32f4xx_hal_rcc.o
arm-none-eabi-gcc -c -mcpu=cortex-m4 -mthumb -mfpu=fpv4-sp-d16 -mfloat-abi=hard -DUSE_HAL_DRIVER -DUSE_FULL_ASSERT -DSTM32F411xE -DDAC_PCM5102A -Isrc -Idrivers/BSP -Idrivers/usb/Core/Inc -Idrivers/usb/Class/AUDIO/Inc -Idrivers/CMSIS/Device/ST/STM32F4xx/Include -Idrivers/CMSIS/Include -Idrivers/STM32F4xx_HAL_Driver/Inc -Idrivers/STM32F4xx_HAL_Driver/Inc/Legacy -O2 -Wall -fdata-sections -ffunction-sections -MMD -MP -MF"build/stm32f4xx_hal_rcc_ex.d" -Wa,-a,-ad,-alms=./build/stm32f4xx_hal_rcc_ex.lst drivers/STM32F4xx_HAL_Driver/Src/stm32f4xx_hal_rcc_ex.c -o build/stm32f4xx_hal_rcc_ex.o
arm-none-eabi-gcc -c -mcpu=cortex-m4 -mthumb -mfpu=fpv4-sp-d16 -mfloat-abi=hard -DUSE_HAL_DRIVER -DUSE_FULL_ASSERT -DSTM32F411xE -DDAC_PCM5102A -Isrc -Idrivers/BSP -Idrivers/usb/Core/Inc -Idrivers/usb/Class/AUDIO/Inc -Idrivers/CMSIS/Device/ST/STM32F4xx/Include -Idrivers/CMSIS/Include -Idrivers/STM32F4xx_HAL_Driver/Inc -Idrivers/STM32F4xx_HAL_Driver/Inc/Legacy -O2 -Wall -fdata-sections -ffunction-sections -MMD -MP -MF"build/stm32f4xx_hal_flash.d" -Wa,-a,-ad,-alms=./build/stm32f4xx_hal_flash.lst drivers/STM32F4xx_HAL_Driver/Src/stm32f4xx_hal_flash.c -o build/stm32f4xx_hal_flash.o
arm-none-eabi-gcc -c -mcpu=cortex-m4 -mthumb -mfpu=fpv4-sp-d16 -mfloat-abi=hard -DUSE_HAL_DRIVER -DUSE_FULL_ASSERT -DSTM32F411xE -DDAC_PCM5102A -Isrc -Idrivers/BSP -Idrivers/usb/Core/Inc -Idrivers/usb/Class/AUDIO/Inc -Idrivers/CMSIS/Device/ST/STM32F4xx/Include -Idrivers/CMSIS/Include -Idrivers/STM32F4xx_HAL_Driver/Inc -Idrivers/STM32F4xx_HAL_Driver/Inc/Legacy -O2 -Wall -fdata-sections -ffunction-sections -MMD -MP -MF"build/stm32f4xx_hal_flash_ex.d" -Wa,-a,-ad,-alms=./build/stm32f4xx_hal_flash_ex.lst drivers/STM32F4xx_HAL_Driver/Src/stm32f4xx_hal_flash_ex.c -o build/stm32f4xx_hal_flash_ex.o
arm-none-eabi-gcc -c -mcpu=cortex-m4 -mthumb -mfpu=fpv4-sp-d16 -mfloat-abi=hard -DUSE_HAL_DRIVER -DUSE_FULL_ASSERT -DSTM32F411xE -DDAC_PCM5102A -Isrc -Idrivers/BSP -Idrivers/usb/Core/Inc -Idrivers/usb/Class/AUDIO/Inc -Idrivers/CMSIS/Device/ST/STM32F4xx/Include -Idrivers/CMSIS/Include -Idrivers/STM32F4xx_HAL_Driver/Inc -Idrivers/STM32F4xx_HAL_Driver/Inc/Legacy -O2 -Wall -fdata-sections -ffunction-sections -MMD -MP -MF"build/stm32f4xx_hal_flash_ramfunc.d" -Wa,-a,-ad,-alms=./build/stm32f4xx_hal_flash_ramfunc.lst drivers/STM32F4xx_HAL_Driver/Src/stm32f4xx_hal_flash_ramfunc.c -o build/stm32f4xx_hal_flash_ramfunc.o
arm-none-eabi-gcc -c -mcpu=cortex-m4 -mthumb -mfpu=fpv4-sp-d16 -mfloat-abi=hard -DUSE_HAL_DRIVER -DUSE_FULL_ASSERT -DSTM32F411xE -DDAC_PCM5102A -Isrc -Idrivers/BSP -Idrivers/usb/Core/Inc -Idrivers/usb/Class/AUDIO/Inc -Idrivers/CMSIS/Device/ST/STM32F4xx/Include -Idrivers/CMSIS/Include -Idrivers/STM32F4xx_HAL_Driver/Inc -Idrivers/STM32F4xx_HAL_Driver/Inc/Legacy -O2 -Wall -fdata-sections -ffunction-sections -MMD -MP -MF"build/stm32f4xx_hal_gpio.d" -Wa,-a,-ad,-alms=./build/stm32f4xx_hal_gpio.lst drivers/STM32F4xx_HAL_Driver/Src/stm32f4xx_hal_gpio.c -o build/stm32f4xx_hal_gpio.o
arm-none-eabi-gcc -c -mcpu=cortex-m4 -mthumb -mfpu=fpv4-sp-d16 -mfloat-abi=hard -DUSE_HAL_DRIVER -DUSE_FULL_ASSERT -DSTM32F411xE -DDAC_PCM5102A -Isrc -Idrivers/BSP -Idrivers/usb/Core/Inc -Idrivers/usb/Class/AUDIO/Inc -Idrivers/CMSIS/Device/ST/STM32F4xx/Include -Idrivers/CMSIS/Include -Idrivers/STM32F4xx_HAL_Driver/Inc -Idrivers/STM32F4xx_HAL_Driver/Inc/Legacy -O2 -Wall -fdata-sections -ffunction-sections -MMD -MP -MF"build/stm32f4xx_hal_dma_ex.d" -Wa,-a,-ad,-alms=./build/stm32f4xx_hal_dma_ex.lst drivers/STM32F4xx_HAL_Driver/Src/stm32f4xx_hal_dma_ex.c -o build/stm32f4xx_hal_dma_ex.o
arm-none-eabi-gcc -c -mcpu=cortex-m4 -mthumb -mfpu=fpv4-sp-d16 -mfloat-abi=hard -DUSE_HAL_DRIVER -DUSE_FULL_ASSERT -DSTM32F411xE -DDAC_PCM5102A -Isrc -Idrivers/BSP -Idrivers/usb/Core/Inc -Idrivers/usb/Class/AUDIO/Inc -Idrivers/CMSIS/Device/ST/STM32F4xx/Include -Idrivers/CMSIS/Include -Idrivers/STM32F4xx_HAL_Driver/Inc -Idrivers/STM32F4xx_HAL_Driver/Inc/Legacy -O2 -Wall -fdata-sections -ffunction-sections -MMD -MP -MF"build/stm32f4xx_hal_dma.d" -Wa,-a,-ad,-alms=./build/stm32f4xx_hal_dma.lst drivers/STM32F4xx_HAL_Driver/Src/stm32f4xx_hal_dma.c -o build/stm32f4xx_hal_dma.o
arm-none-eabi-gcc -c -mcpu=cortex-m4 -mthumb -mfpu=fpv4-sp-d16 -mfloat-abi=hard -DUSE_HAL_DRIVER -DUSE_FULL_ASSERT -DSTM32F411xE -DDAC_PCM5102A -Isrc -Idrivers/BSP -Idrivers/usb/Core/Inc -Idrivers/usb/Class/AUDIO/Inc -Idrivers/CMSIS/Device/ST/STM32F4xx/Include -Idrivers/CMSIS/Include -Idrivers/STM32F4xx_HAL_Driver/Inc -Idrivers/STM32F4xx_HAL_Driver/Inc/Legacy -O2 -Wall -fdata-sections -ffunction-sections -MMD -MP -MF"build/stm32f4xx_hal_pwr.d" -Wa,-a,-ad,-alms=./build/stm32f4xx_hal_pwr.lst drivers/STM32F4xx_HAL_Driver/Src/stm32f4xx_hal_pwr.c -o build/stm32f4xx_hal_pwr.o
arm-none-eabi-gcc -c -mcpu=cortex-m4 -mthumb -mfpu=fpv4-sp-d16 -mfloat-abi=hard -DUSE_HAL_DRIVER -DUSE_FULL_ASSERT -DSTM32F411xE -DDAC_PCM5102A -Isrc -Idrivers/BSP -Idrivers/usb/Core/Inc -Idrivers/usb/Class/AUDIO/Inc -Idrivers/CMSIS/Device/ST/STM32F4xx/Include -Idrivers/CMSIS/Include -Idrivers/STM32F4xx_HAL_Driver/Inc -Idrivers/STM32F4xx_HAL_Driver/Inc/Legacy -O2 -Wall -fdata-sections -ffunction-sections -MMD -MP -MF"build/stm32f4xx_hal_uart.d" -Wa,-a,-ad,-alms=./build/stm32f4xx_hal_uart.lst drivers/STM32F4xx_HAL_Driver/Src/stm32f4xx_hal_uart.c -o build/stm32f4xx_hal_uart.o
arm-none-eabi-gcc -c -mcpu=cortex-m4 -mthumb -mfpu=fpv4-sp-d16 -mfloat-abi=hard -DUSE_HAL_DRIVER -DUSE_FULL_ASSERT -DSTM32F411xE -DDAC_PCM5102A -Isrc -Idrivers/BSP -Idrivers/usb/Core/Inc -Idrivers/usb/Class/AUDIO/Inc -Idrivers/CMSIS/Device/ST/STM32F4xx/Include -Idrivers/CMSIS/Include -Idrivers/STM32F4xx_HAL_Driver/Inc -Idrivers/STM32F4xx_HAL_Driver/Inc/Legacy -O2 -Wall -fdata-sections -ffunction-sections -MMD -MP -MF"build/stm32f4xx_hal_pwr_ex.d" -Wa,-a,-ad,-alms=./build/stm32f4xx_hal_pwr_ex.lst drivers/STM32F4xx_HAL_Driver/Src/stm32f4xx_hal_pwr_ex.c -o build/stm32f4xx_hal_pwr_ex.o
arm-none-eabi-gcc -c -mcpu=cortex-m4 -mthumb -mfpu=fpv4-sp-d16 -mfloat-abi=hard -DUSE_HAL_DRIVER -DUSE_FULL_ASSERT -DSTM32F411xE -DDAC_PCM5102A -Isrc -Idrivers/BSP -Idrivers/usb/Core/Inc -Idrivers/usb/Class/AUDIO/Inc -Idrivers/CMSIS/Device/ST/STM32F4xx/Include -Idrivers/CMSIS/Include -Idrivers/STM32F4xx_HAL_Driver/Inc -Idrivers/STM32F4xx_HAL_Driver/Inc/Legacy -O2 -Wall -fdata-sections -ffunction-sections -MMD -MP -MF"build/stm32f4xx_hal_cortex.d" -Wa,-a,-ad,-alms=./build/stm32f4xx_hal_cortex.lst drivers/STM32F4xx_HAL_Driver/Src/stm32f4xx_hal_cortex.c -o build/stm32f4xx_hal_cortex.o
arm-none-eabi-gcc -c -mcpu=cortex-m4 -mthumb -mfpu=fpv4-sp-d16 -mfloat-abi=hard -DUSE_HAL_DRIVER -DUSE_FULL_ASSERT -DSTM32F411xE -DDAC_PCM5102A -Isrc -Idrivers/BSP -Idrivers/usb/Core/Inc -Idrivers/usb/Class/AUDIO/Inc -Idrivers/CMSIS/Device/ST/STM32F4xx/Include -Idrivers/CMSIS/Include -Idrivers/STM32F4xx_HAL_Driver/Inc -Idrivers/STM32F4xx_HAL_Driver/Inc/Legacy -O2 -Wall -fdata-sections -ffunction-sections -MMD -MP -MF"build/stm32f4xx_hal.d" -Wa,-a,-ad,-alms=./build/stm32f4xx_hal.lst drivers/STM32F4xx_HAL_Driver/Src/stm32f4xx_hal.c -o build/stm32f4xx_hal.o
arm-none-eabi-gcc -c -mcpu=cortex-m4 -mthumb -mfpu=fpv4-sp-d16 -mfloat-abi=hard -DUSE_HAL_DRIVER -DUSE_FULL_ASSERT -DSTM32F411xE -DDAC_PCM5102A -Isrc -Idrivers/BSP -Idrivers/usb/Core/Inc -Idrivers/usb/Class/AUDIO/Inc -Idrivers/CMSIS/Device/ST/STM32F4xx/Include -Idrivers/CMSIS/Include -Idrivers/STM32F4xx_HAL_Driver/Inc -Idrivers/STM32F4xx_HAL_Driver/Inc/Legacy -O2 -Wall -fdata-sections -ffunction-sections -MMD -MP -MF"build/stm32f4xx_hal_exti.d" -Wa,-a,-ad,-alms=./build/stm32f4xx_hal_exti.lst drivers/STM32F4xx_HAL_Driver/Src/stm32f4xx_hal_exti.c -o build/stm32f4xx_hal_exti.o
arm-none-eabi-gcc -x assembler-with-cpp -c -mcpu=cortex-m4 -mthumb -mfpu=fpv4-sp-d16 -mfloat-abi=hard -DUSE_HAL_DRIVER -DUSE_FULL_ASSERT -DSTM32F411xE -DDAC_PCM5102A -Isrc -Idrivers/BSP -Idrivers/usb/Core/Inc -Idrivers/usb/Class/AUDIO/Inc -Idrivers/CMSIS/Device/ST/STM32F4xx/Include -Idrivers/CMSIS/Include -Idrivers/STM32F4xx_HAL_Driver/Inc -Idrivers/STM32F4xx_HAL_Driver/Inc/Legacy -O2 -Wall -fdata-sections -ffunction-sections -MMD -MP -MF"build/startup_stm32f411ceux.d" startup_stm32f411ceux.s -o build/startup_stm32f411ceux.o
arm-none-eabi-gcc ./build/main.o ./build/usart.o ./build/usbd_conf.o ./build/usbd_desc.o ./build/usbd_audio_if.o ./build/stm32f4xx_it.o ./build/system_stm32f4xx.o ./build/usbd_core.o ./build/usbd_ctlreq.o ./build/usbd_ioreq.o ./build/usbd_audio.o ./build/bsp_misc.o ./build/bsp_audio.o ./build/stm32f4xx_hal_pcd.o ./build/stm32f4xx_hal_pcd_ex.o ./build/stm32f4xx_ll_usb.o ./build/stm32f4xx_hal_i2s.o ./build/stm32f4xx_hal_i2s_ex.o ./build/stm32f4xx_hal_tim.o ./build/stm32f4xx_hal_tim_ex.o ./build/stm32f4xx_hal_rcc.o ./build/stm32f4xx_hal_rcc_ex.o ./build/stm32f4xx_hal_flash.o ./build/stm32f4xx_hal_flash_ex.o ./build/stm32f4xx_hal_flash_ramfunc.o ./build/stm32f4xx_hal_gpio.o ./build/stm32f4xx_hal_dma_ex.o ./build/stm32f4xx_hal_dma.o ./build/stm32f4xx_hal_pwr.o ./build/stm32f4xx_hal_uart.o ./build/stm32f4xx_hal_pwr_ex.o ./build/stm32f4xx_hal_cortex.o ./build/stm32f4xx_hal.o ./build/stm32f4xx_hal_exti.o ./build/startup_stm32f411ceux.o -mcpu=cortex-m4 -mthumb -mfpu=fpv4-sp-d16 -mfloat-abi=hard -specs=nano.specs  -u _printf_float -TSTM32F411CEUX_FLASH.ld  -lc -lm -lnosys  -Wl,-Map=./build/usb_audio_i2s.map,--cref -Wl,--gc-sections -o build/usb_audio_i2s.elf
/opt/st/stm32cubeide_1.19.0/plugins/com.st.stm32cube.ide.mcu.externaltools.gnu-tools-for-stm32.13.3.rel1.linux64_1.0.0.202410170706/tools/bin/../lib/gcc/arm-none-eabi/13.3.1/../../../../arm-none-eabi/bin/ld: /opt/st/stm32cubeide_1.19.0/plugins/com.st.stm32cube.ide.mcu.externaltools.gnu-tools-for-stm32.13.3.rel1.linux64_1.0.0.202410170706/tools/bin/../lib/gcc/arm-none-eabi/13.3.1/../../../../arm-none-eabi/lib/thumb/v7e-m+fp/hard/libc_nano.a(libc_a-closer.o): in function `_close_r':
(.text._close_r+0xc): warning: _close is not implemented and will always fail
/opt/st/stm32cubeide_1.19.0/plugins/com.st.stm32cube.ide.mcu.externaltools.gnu-tools-for-stm32.13.3.rel1.linux64_1.0.0.202410170706/tools/bin/../lib/gcc/arm-none-eabi/13.3.1/../../../../arm-none-eabi/bin/ld: /opt/st/stm32cubeide_1.19.0/plugins/com.st.stm32cube.ide.mcu.externaltools.gnu-tools-for-stm32.13.3.rel1.linux64_1.0.0.202410170706/tools/bin/../lib/gcc/arm-none-eabi/13.3.1/../../../../arm-none-eabi/lib/thumb/v7e-m+fp/hard/libc_nano.a(libc_a-closer.o): note: the message above does not take linker garbage collection into account
/opt/st/stm32cubeide_1.19.0/plugins/com.st.stm32cube.ide.mcu.externaltools.gnu-tools-for-stm32.13.3.rel1.linux64_1.0.0.202410170706/tools/bin/../lib/gcc/arm-none-eabi/13.3.1/../../../../arm-none-eabi/bin/ld: /opt/st/stm32cubeide_1.19.0/plugins/com.st.stm32cube.ide.mcu.externaltools.gnu-tools-for-stm32.13.3.rel1.linux64_1.0.0.202410170706/tools/bin/../lib/gcc/arm-none-eabi/13.3.1/../../../../arm-none-eabi/lib/thumb/v7e-m+fp/hard/libc_nano.a(libc_a-fstatr.o): in function `_fstat_r':
(.text._fstat_r+0xe): warning: _fstat is not implemented and will always fail
/opt/st/stm32cubeide_1.19.0/plugins/com.st.stm32cube.ide.mcu.externaltools.gnu-tools-for-stm32.13.3.rel1.linux64_1.0.0.202410170706/tools/bin/../lib/gcc/arm-none-eabi/13.3.1/../../../../arm-none-eabi/bin/ld: /opt/st/stm32cubeide_1.19.0/plugins/com.st.stm32cube.ide.mcu.externaltools.gnu-tools-for-stm32.13.3.rel1.linux64_1.0.0.202410170706/tools/bin/../lib/gcc/arm-none-eabi/13.3.1/../../../../arm-none-eabi/lib/thumb/v7e-m+fp/hard/libc_nano.a(libc_a-fstatr.o): note: the message above does not take linker garbage collection into account
/opt/st/stm32cubeide_1.19.0/plugins/com.st.stm32cube.ide.mcu.externaltools.gnu-tools-for-stm32.13.3.rel1.linux64_1.0.0.202410170706/tools/bin/../lib/gcc/arm-none-eabi/13.3.1/../../../../arm-none-eabi/bin/ld: /opt/st/stm32cubeide_1.19.0/plugins/com.st.stm32cube.ide.mcu.externaltools.gnu-tools-for-stm32.13.3.rel1.linux64_1.0.0.202410170706/tools/bin/../lib/gcc/arm-none-eabi/13.3.1/../../../../arm-none-eabi/lib/thumb/v7e-m+fp/hard/libc_nano.a(libc_a-signalr.o): in function `_getpid_r':
(.text._getpid_r+0x0): warning: _getpid is not implemented and will always fail
/opt/st/stm32cubeide_1.19.0/plugins/com.st.stm32cube.ide.mcu.externaltools.gnu-tools-for-stm32.13.3.rel1.linux64_1.0.0.202410170706/tools/bin/../lib/gcc/arm-none-eabi/13.3.1/../../../../arm-none-eabi/bin/ld: /opt/st/stm32cubeide_1.19.0/plugins/com.st.stm32cube.ide.mcu.externaltools.gnu-tools-for-stm32.13.3.rel1.linux64_1.0.0.202410170706/tools/bin/../lib/gcc/arm-none-eabi/13.3.1/../../../../arm-none-eabi/lib/thumb/v7e-m+fp/hard/libc_nano.a(libc_a-signalr.o): note: the message above does not take linker garbage collection into account
/opt/st/stm32cubeide_1.19.0/plugins/com.st.stm32cube.ide.mcu.externaltools.gnu-tools-for-stm32.13.3.rel1.linux64_1.0.0.202410170706/tools/bin/../lib/gcc/arm-none-eabi/13.3.1/../../../../arm-none-eabi/bin/ld: /opt/st/stm32cubeide_1.19.0/plugins/com.st.stm32cube.ide.mcu.externaltools.gnu-tools-for-stm32.13.3.rel1.linux64_1.0.0.202410170706/tools/bin/../lib/gcc/arm-none-eabi/13.3.1/../../../../arm-none-eabi/lib/thumb/v7e-m+fp/hard/libc_nano.a(libc_a-isattyr.o): in function `_isatty_r':
(.text._isatty_r+0xc): warning: _isatty is not implemented and will always fail
/opt/st/stm32cubeide_1.19.0/plugins/com.st.stm32cube.ide.mcu.externaltools.gnu-tools-for-stm32.13.3.rel1.linux64_1.0.0.202410170706/tools/bin/../lib/gcc/arm-none-eabi/13.3.1/../../../../arm-none-eabi/bin/ld: /opt/st/stm32cubeide_1.19.0/plugins/com.st.stm32cube.ide.mcu.externaltools.gnu-tools-for-stm32.13.3.rel1.linux64_1.0.0.202410170706/tools/bin/../lib/gcc/arm-none-eabi/13.3.1/../../../../arm-none-eabi/lib/thumb/v7e-m+fp/hard/libc_nano.a(libc_a-isattyr.o): note: the message above does not take linker garbage collection into account
/opt/st/stm32cubeide_1.19.0/plugins/com.st.stm32cube.ide.mcu.externaltools.gnu-tools-for-stm32.13.3.rel1.linux64_1.0.0.202410170706/tools/bin/../lib/gcc/arm-none-eabi/13.3.1/../../../../arm-none-eabi/bin/ld: /opt/st/stm32cubeide_1.19.0/plugins/com.st.stm32cube.ide.mcu.externaltools.gnu-tools-for-stm32.13.3.rel1.linux64_1.0.0.202410170706/tools/bin/../lib/gcc/arm-none-eabi/13.3.1/../../../../arm-none-eabi/lib/thumb/v7e-m+fp/hard/libc_nano.a(libc_a-signalr.o): in function `_kill_r':
(.text._kill_r+0xe): warning: _kill is not implemented and will always fail
/opt/st/stm32cubeide_1.19.0/plugins/com.st.stm32cube.ide.mcu.externaltools.gnu-tools-for-stm32.13.3.rel1.linux64_1.0.0.202410170706/tools/bin/../lib/gcc/arm-none-eabi/13.3.1/../../../../arm-none-eabi/bin/ld: /opt/st/stm32cubeide_1.19.0/plugins/com.st.stm32cube.ide.mcu.externaltools.gnu-tools-for-stm32.13.3.rel1.linux64_1.0.0.202410170706/tools/bin/../lib/gcc/arm-none-eabi/13.3.1/../../../../arm-none-eabi/lib/thumb/v7e-m+fp/hard/libc_nano.a(libc_a-signalr.o): note: the message above does not take linker garbage collection into account
/opt/st/stm32cubeide_1.19.0/plugins/com.st.stm32cube.ide.mcu.externaltools.gnu-tools-for-stm32.13.3.rel1.linux64_1.0.0.202410170706/tools/bin/../lib/gcc/arm-none-eabi/13.3.1/../../../../arm-none-eabi/bin/ld: /opt/st/stm32cubeide_1.19.0/plugins/com.st.stm32cube.ide.mcu.externaltools.gnu-tools-for-stm32.13.3.rel1.linux64_1.0.0.202410170706/tools/bin/../lib/gcc/arm-none-eabi/13.3.1/../../../../arm-none-eabi/lib/thumb/v7e-m+fp/hard/libc_nano.a(libc_a-lseekr.o): in function `_lseek_r':
(.text._lseek_r+0x10): warning: _lseek is not implemented and will always fail
/opt/st/stm32cubeide_1.19.0/plugins/com.st.stm32cube.ide.mcu.externaltools.gnu-tools-for-stm32.13.3.rel1.linux64_1.0.0.202410170706/tools/bin/../lib/gcc/arm-none-eabi/13.3.1/../../../../arm-none-eabi/bin/ld: /opt/st/stm32cubeide_1.19.0/plugins/com.st.stm32cube.ide.mcu.externaltools.gnu-tools-for-stm32.13.3.rel1.linux64_1.0.0.202410170706/tools/bin/../lib/gcc/arm-none-eabi/13.3.1/../../../../arm-none-eabi/lib/thumb/v7e-m+fp/hard/libc_nano.a(libc_a-lseekr.o): note: the message above does not take linker garbage collection into account
/opt/st/stm32cubeide_1.19.0/plugins/com.st.stm32cube.ide.mcu.externaltools.gnu-tools-for-stm32.13.3.rel1.linux64_1.0.0.202410170706/tools/bin/../lib/gcc/arm-none-eabi/13.3.1/../../../../arm-none-eabi/bin/ld: /opt/st/stm32cubeide_1.19.0/plugins/com.st.stm32cube.ide.mcu.externaltools.gnu-tools-for-stm32.13.3.rel1.linux64_1.0.0.202410170706/tools/bin/../lib/gcc/arm-none-eabi/13.3.1/../../../../arm-none-eabi/lib/thumb/v7e-m+fp/hard/libc_nano.a(libc_a-readr.o): in function `_read_r':
(.text._read_r+0x10): warning: _read is not implemented and will always fail
/opt/st/stm32cubeide_1.19.0/plugins/com.st.stm32cube.ide.mcu.externaltools.gnu-tools-for-stm32.13.3.rel1.linux64_1.0.0.202410170706/tools/bin/../lib/gcc/arm-none-eabi/13.3.1/../../../../arm-none-eabi/bin/ld: /opt/st/stm32cubeide_1.19.0/plugins/com.st.stm32cube.ide.mcu.externaltools.gnu-tools-for-stm32.13.3.rel1.linux64_1.0.0.202410170706/tools/bin/../lib/gcc/arm-none-eabi/13.3.1/../../../../arm-none-eabi/lib/thumb/v7e-m+fp/hard/libc_nano.a(libc_a-readr.o): note: the message above does not take linker garbage collection into account
/opt/st/stm32cubeide_1.19.0/plugins/com.st.stm32cube.ide.mcu.externaltools.gnu-tools-for-stm32.13.3.rel1.linux64_1.0.0.202410170706/tools/bin/../lib/gcc/arm-none-eabi/13.3.1/../../../../arm-none-eabi/bin/ld: /opt/st/stm32cubeide_1.19.0/plugins/com.st.stm32cube.ide.mcu.externaltools.gnu-tools-for-stm32.13.3.rel1.linux64_1.0.0.202410170706/tools/bin/../lib/gcc/arm-none-eabi/13.3.1/../../../../arm-none-eabi/lib/thumb/v7e-m+fp/hard/libc_nano.a(libc_a-writer.o): in function `_write_r':
(.text._write_r+0x10): warning: _write is not implemented and will always fail
/opt/st/stm32cubeide_1.19.0/plugins/com.st.stm32cube.ide.mcu.externaltools.gnu-tools-for-stm32.13.3.rel1.linux64_1.0.0.202410170706/tools/bin/../lib/gcc/arm-none-eabi/13.3.1/../../../../arm-none-eabi/bin/ld: /opt/st/stm32cubeide_1.19.0/plugins/com.st.stm32cube.ide.mcu.externaltools.gnu-tools-for-stm32.13.3.rel1.linux64_1.0.0.202410170706/tools/bin/../lib/gcc/arm-none-eabi/13.3.1/../../../../arm-none-eabi/lib/thumb/v7e-m+fp/hard/libc_nano.a(libc_a-writer.o): note: the message above does not take linker garbage collection into account
arm-none-eabi-size build/usb_audio_i2s.elf
   text	   data	    bss	    dec	    hex	filename
  38616	    800	   5160	  44576	   ae20	build/usb_audio_i2s.elf
arm-none-eabi-objcopy -O ihex build/usb_audio_i2s.elf build/usb_audio_i2s.hex
arm-none-eabi-objcopy -O binary -S build/usb_audio_i2s.elf build/usb_audio_i2s.bin	
tobias@pc14400:~/Downloads/STM32F411_USB_AUDIO_DAC-main$

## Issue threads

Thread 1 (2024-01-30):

I need your help please

cavl3108, 2024-01-30:
Hello, what is the possibility that you can help me set up or develop a code based on this, even if it is necessary to pay you, I need, based on the black pill card and the pcm5102, with the USB audio protocol to create a kind of crossover and digital graphic equalizer where it makes use of the DSP core integrated into the card and the control of the band gains is carried out through a graphic interface, either digital through an Android application or an analog interface, please I need your help.

TobiasVanDyk, 2024-01-30:
Hi

The code to do all of that is already available if you use another ARM-based MCU namely an H7-based [Teensy 4x](https://www.pjrc.com/) - have you heard about it?

Recent STM examples seems to move away from audio DSP's

Please see the [Teensy Audio System Design Tool](https://www.pjrc.com/teensy/gui/ ) and the [Teensy forum](https://forum.pjrc.com/)

TobiasVanDyk, 2024-01-30:
If you post the following on the Teensy forum you will get a good reaction from the members there:

Hello, I am new to the Teensy world and before I purchase any, I would like to know if what I need already exist and/or is possible?

"I need help to set up or develop a code based on the Teensy 4x and a PCM5102, with the USB audio protocol to create a kind of crossover and digital graphic equalizer where it makes use of the DSP core integrated into the card and the control of the band gains is carried out through a graphic interface, either digital through an Android application or an analog interface"

Closed 2024-11-12.

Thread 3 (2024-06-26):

master clock frequency

Jente105, 2024-06-26:
firstly, thanks for your work on this subject.
I was looking to replace the PCM5102a with a better dac. I noticed that the STM32F411xE configuration could provide the masterclock. what would the frequency at the rated sample frequencies(44.1, 48 and 96 kHz) of your firmware be when masterclock generation is enabled?

thanks,

TobiasVanDyk, 2024-06-26:
Hi

Yikes those calculations are above my paygrade I’m afraid

The best is to post your query on the origin of the source code that I am using which is
https://github.com/har-in-air/STM32F411_USB_AUDIO_DAC
and
https://github.com/dragonman225/stm32f469-usbaudio

If you get to a working configuration with an external i2s clock please let me know the details..

Best wishes
Tobias van Dyk

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

TobiasVanDyk, 2024-06-26:
Hi

I attach the SCK frequencies from the datasheet page 24

Best wishes
TvD

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

TobiasVanDyk, 2024-06-26:
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

TobiasVanDyk, 2024-07-21:
Also check [**issue #26**](https://github.com/har-in-air/STM32F411_USB_AUDIO_DAC/issues/)
"As per reference manual RM0383 for F411, when MCLK is enabled, MCLK = 256 x Fs (page 585)I've added a comment in the Makefile."

Closed 2024-11-12.

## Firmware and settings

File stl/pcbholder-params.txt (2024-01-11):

// <params> for STM32F411 Black Pill
pcbThickness = 1.55;
pcbWidth = 21.5;
pcbLength = 53;
pcbOffsetFromBase = 10;
tolerance = 0.05;
wall = 1.5;
ridge = 1.5;
screwSize = 3;
screwHoleWall = 2;
screwButtressWall = 10;
screw1DistanceFromFront = 5;
screw2DistanceFromFront = 35;
screwDistanceFromPCB = 5;
rearHole = 10;
holeDistanceFromWall = 5;
// </params>


// <params> for STM32F103 Blue Pill
pcbThickness = 1.55;
pcbWidth = 22.7;
pcbLength = 52.8;
pcbOffsetFromBase = 2.6;
tolerance = 0.05;
wall = 1.5;
ridge = 1.5;
screwSize = 3.5;
screwHoleWall = 2;
screwButtressWall = 3;
screw1DistanceFromFront = 5;
screw2DistanceFromFront = 50;
screwDistanceFromPCB = 6;
rearHole = 10;
holeDistanceFromWall = 4;
// </params>

// <params> for Teensy 4.1
pcbThickness = 1.80;
pcbWidth = 18.0;
pcbLength = 61.0;
pcbOffsetFromBase = 2.6;
tolerance = 0.05;
wall = 1.5;
ridge = 1.5;
screwSize = 3.5;
screwHoleWall = 2;
screwButtressWall = 3;
screw1DistanceFromFront = 5;
screw2DistanceFromFront = 50;
screwDistanceFromPCB = 6;
rearHole = 10;
holeDistanceFromWall = 4;
// </params>

// <params> for Pi Pico 
// Print Pico at 1.02 scaling if l1.50 PCB used w=21.624 h=52.224
pcbThickness = 1.50;  
pcbWidth = 21.52.22;
pcbLength = 51.2;
pcbOffsetFromBase = 2.6;
tolerance = 0.05;
wall = 1.5;
ridge = 1.5;
screwSize = 3.5;
screwHoleWall = 2;
screwButtressWall = 3;
screw1DistanceFromFront = 5;
screw2DistanceFromFront = 50;
screwDistanceFromPCB = 6;
rearHole = 10;
holeDistanceFromWall = 4;
// </params>
